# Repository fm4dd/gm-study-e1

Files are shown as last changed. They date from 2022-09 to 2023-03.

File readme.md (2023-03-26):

## GM-STUDY-E1

### Description

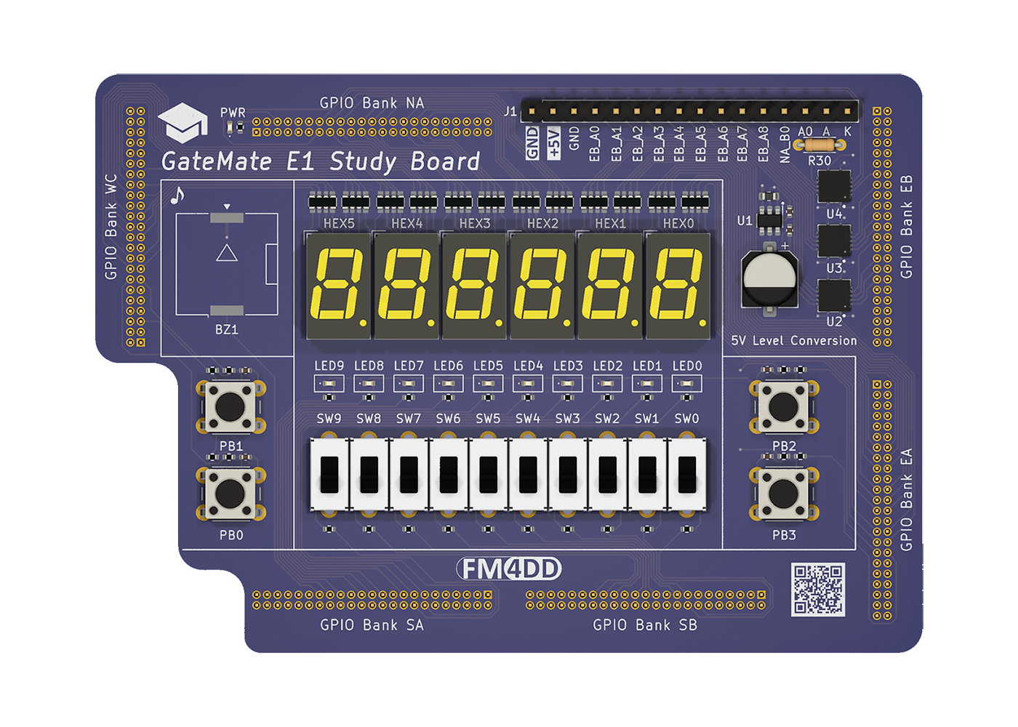
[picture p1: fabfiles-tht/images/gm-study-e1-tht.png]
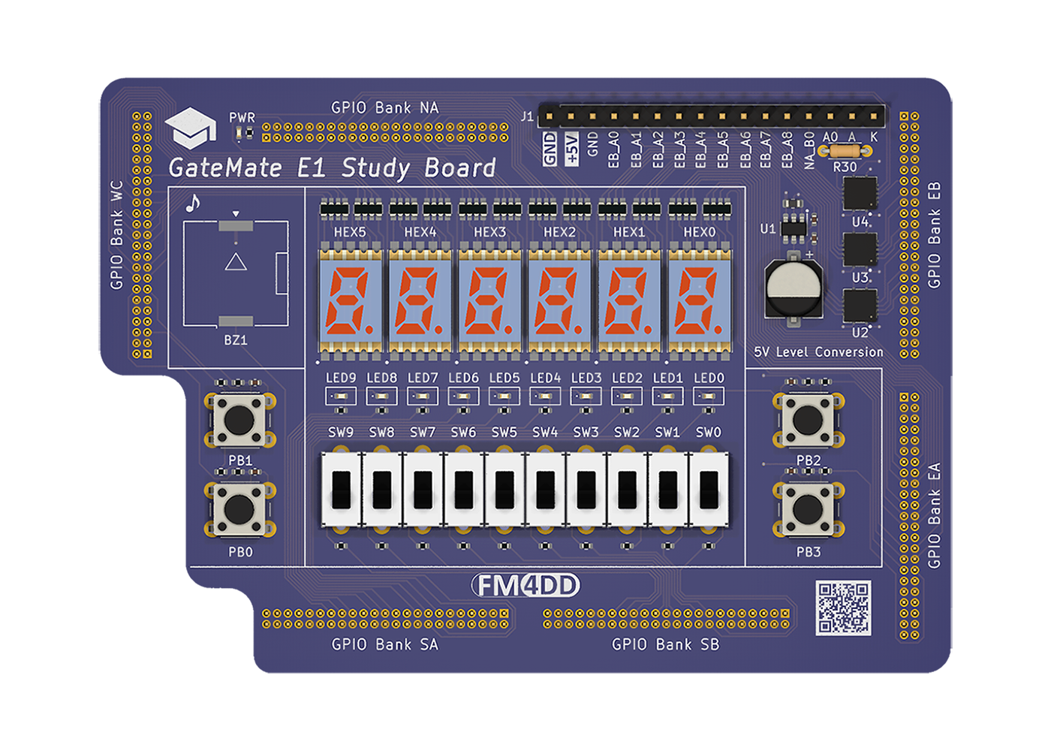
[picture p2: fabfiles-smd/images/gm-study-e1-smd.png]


The gm-study-e1 board is an application module board for the <a href="https://www.colognechip.com/programmable-logic/gatemate-evaluation-board/">GateMate FPGA evaluation board E1</a>, made by <a href="https://www.colognechip.com/">Cologne Chip</a>. It connects to the evaluation board through all six GPIO headers, and its main feature are the input/output components similar to popular FPGA trainer boards used for classroom teaching in electrical engineering and embedded systems education (e.g. Digilent Basys or Altera DE10-lite). These boards were created after successful design tests of the <a href="https://github.com/fm4dd/gm-proto-e1">gm-proto-e1</a> boards. The "gm-proto-e1" boards have only a few basic I/O, but provide a 2.54mm prototyping area for experimentation with GateMate E1.

### Overview

The gm-study-e1 boards provide:
- 4x push buttons
- 10x slide switches
- 10x LED
- 6x 7-Segment display modules (non-multiplexed)
- 1x 4 Khz buzzer
- J1 2.54mm pin header with 5V signal translation

The J1 pin header and pinout can connect 5V HD44780 character LCD display modules, or interface with breadboards for prototyping. There, the FPGA 2.5V IO signals are translated into 5V TTL levels, which can be used with an Arduino.

This design is registered under the OSHWA Open Source Hardware Self-Certification:  


### Hardware Versions

Two board variants have been designed: SMD, using 0.28" SMD 7-Segment modules, and THT for using slightly bigger 0.3" through-hole 7-Segment modules. For THT components, great care needs to be taken to cut pins flush during soldering, and prevent them from reaching components of the evaluation board below. The 1.27mm pitch GPIO connectors are offered with different distance spacers (2, 2.5 and 5mm), and the standard spacers achieve only 5mm total clearance.

Both gm-study-e1 application boards have been designed as a 100x70mm double-layer PCB with precision alignment of the six 46-pin 1.27mm pitch GPIO bank connectors (mates all 276 pins with the GateMate FPGA evaluation board E1 V3.1B).

#### Through-hole Design:

| Version | Gerber | Schema |
|---|---|---|
| 1.1 |[2030325-gm-study-e1-tht-gerber.zip](fabfiles-tht/v11/20230325-gm-study-e1-tht-gerber.zip) | [20230325-gm-proto-e1-schematic.pdf](fabfiles-tht/v11/20230325-gm-study-e1-tht-schematic.pdf) |

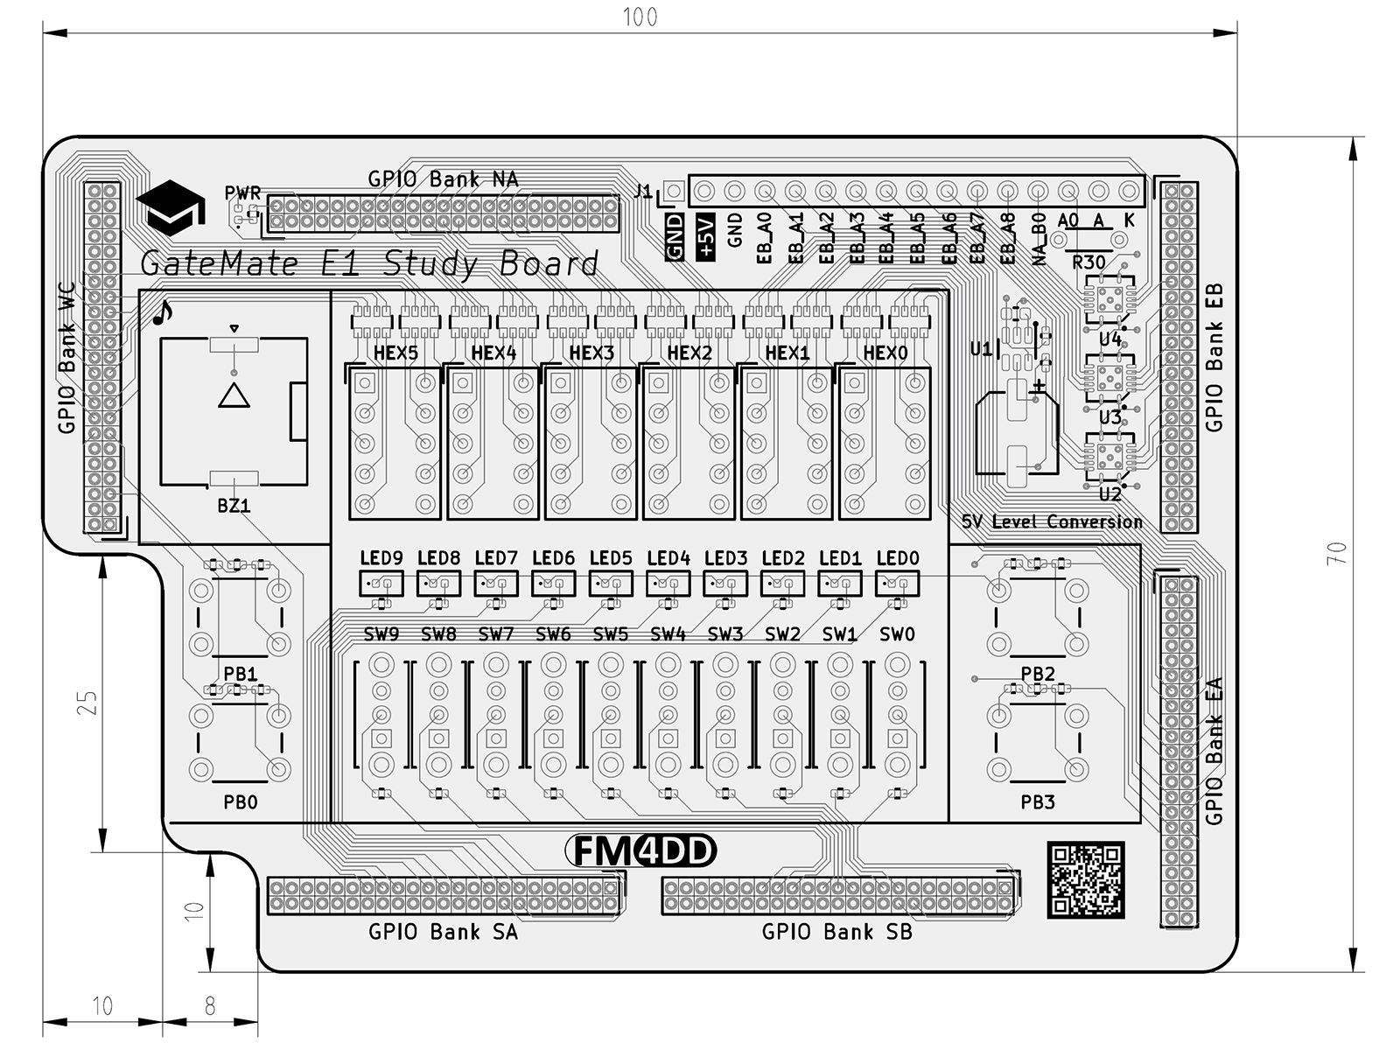
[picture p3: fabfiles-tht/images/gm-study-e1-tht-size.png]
 
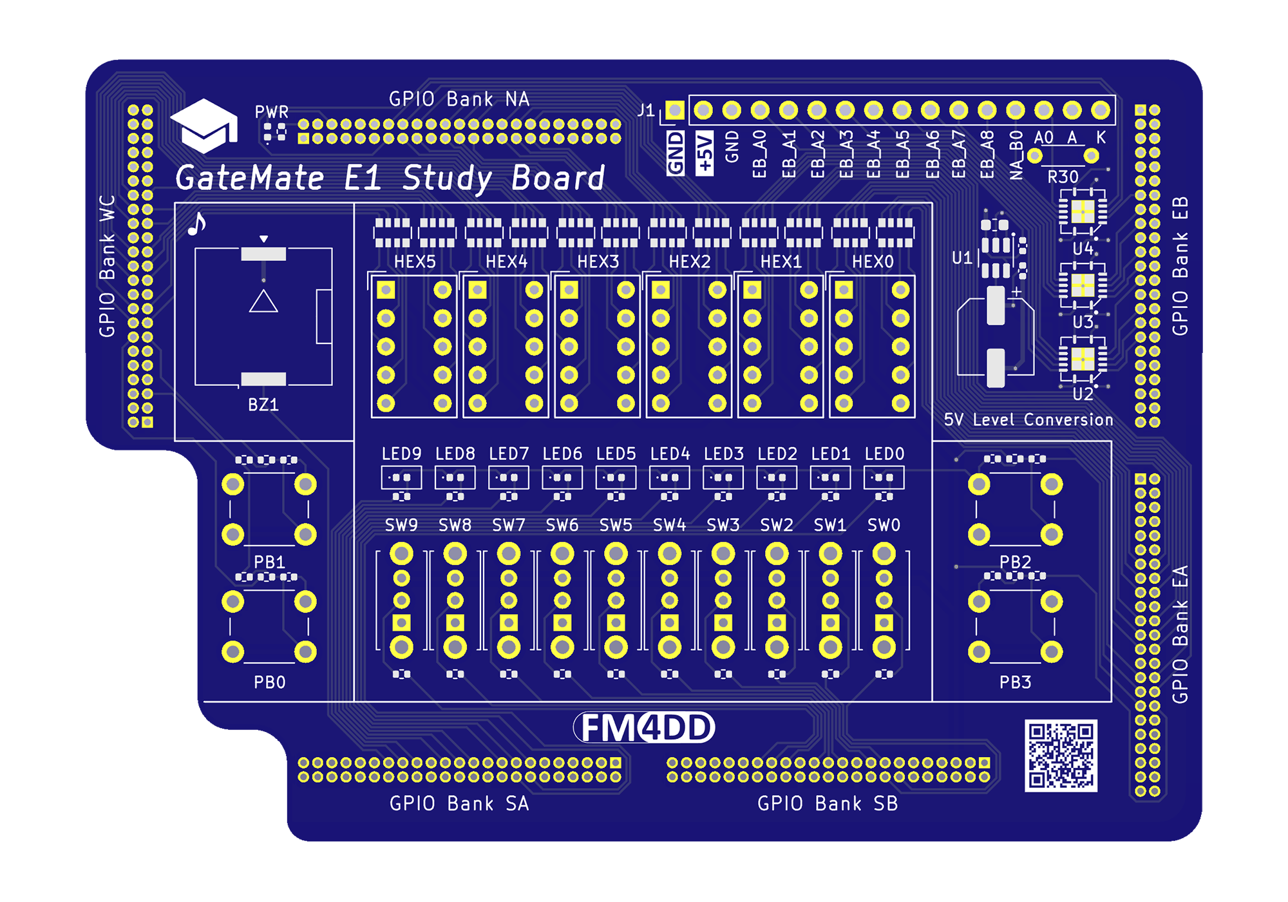
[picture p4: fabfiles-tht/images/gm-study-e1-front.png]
 

#### Surface-Mount Design:

| Version | Gerber | Schema |
|---|---|---|
| 1.1 |[20230326-gm-study-e1-smd-gerber.zip](fabfiles-smd/v11/20230326-gm-study-e1-smd-gerber.zip) | [20230326-gm-study-e1-smd-schematic.pdf](fabfiles-smd/v11/20230326-gm-study-e1-smd-schematic.pdf) |

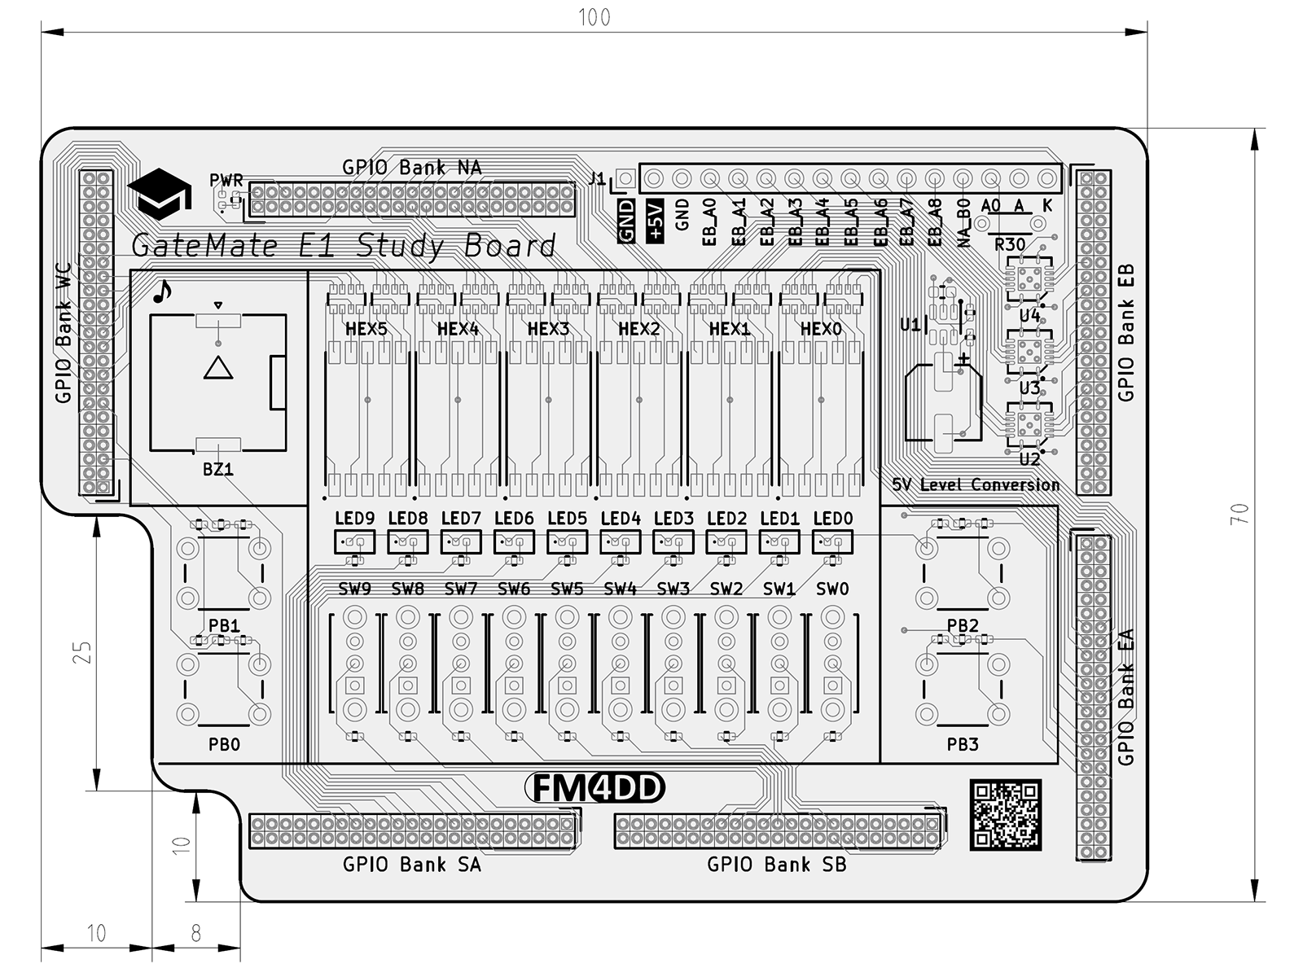
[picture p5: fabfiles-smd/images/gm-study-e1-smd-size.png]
 
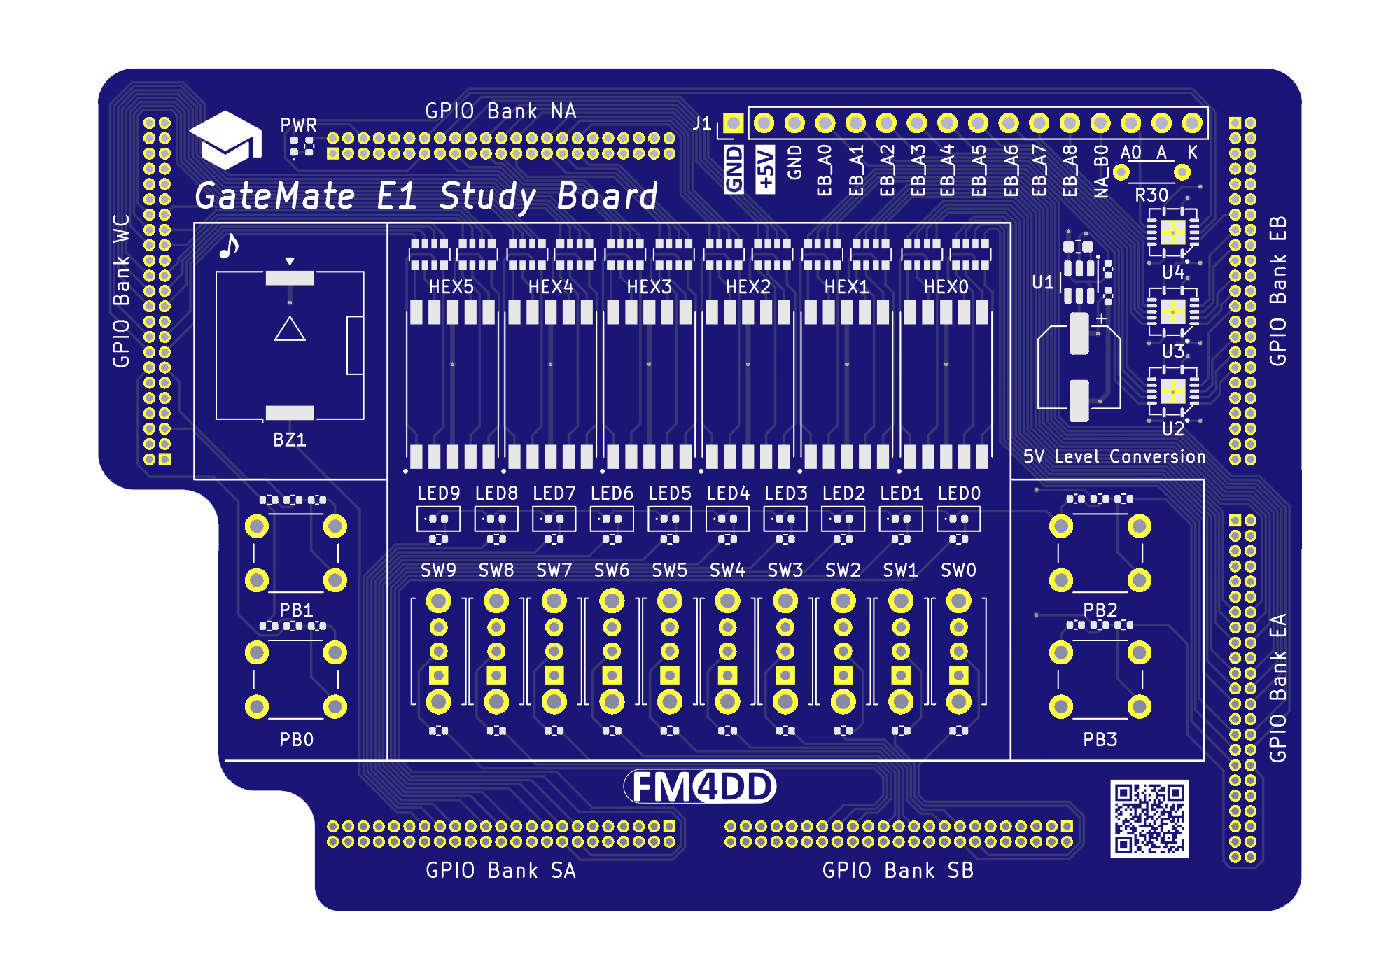
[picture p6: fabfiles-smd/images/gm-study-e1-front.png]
 

### Pin Assignments

Both variants (THT and SMD) have identical pinout, listed in [pin-assignment.md](pin-assignment.md).
They share a single constraints assignment file, located here: [gm-study-e1.ccf](examples/gm-study-e1.ccf)

### Example Code

The following code examples demonstrate the board input/output components for quick verification. The code has been tested with the pre-compiled opensource toolchain released through the GateMate support site at <a href="https://www.colognechip.com/mygatemate/">https://www.colognechip.com/mygatemate/</a>

| Language | Folder | Description |
|---|---|---|
| Verilog  |[blink](examples/blink) | blinks five LED's in a alternating pattern |
| Verilog  |[count](examples/count) | binary counter displayed on ten LED and six 7-Segment digits |
| Verilog  |[button](examples/button) | push button press changes LED frequency and light move direction  |
| Verilog  |[switch](examples/switch) | each slide switch turns its corresponding LED on or off |
| Verilog  |[sound](examples/sound) | play a song on the buzzer, show notes on LED and 7-segment digits |

### Board Pictures

The gm-study-e1 application board, running the switch demo.
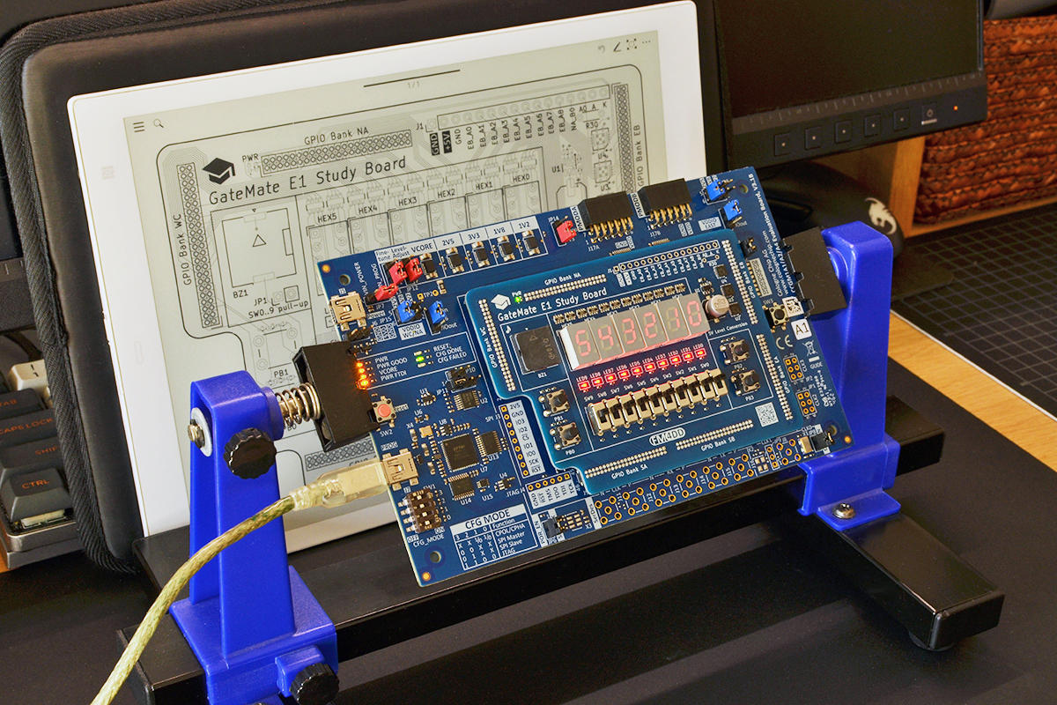
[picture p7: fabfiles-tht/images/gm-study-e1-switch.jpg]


The gm-study-e1 application board has been designed with KiCad version 6.0.
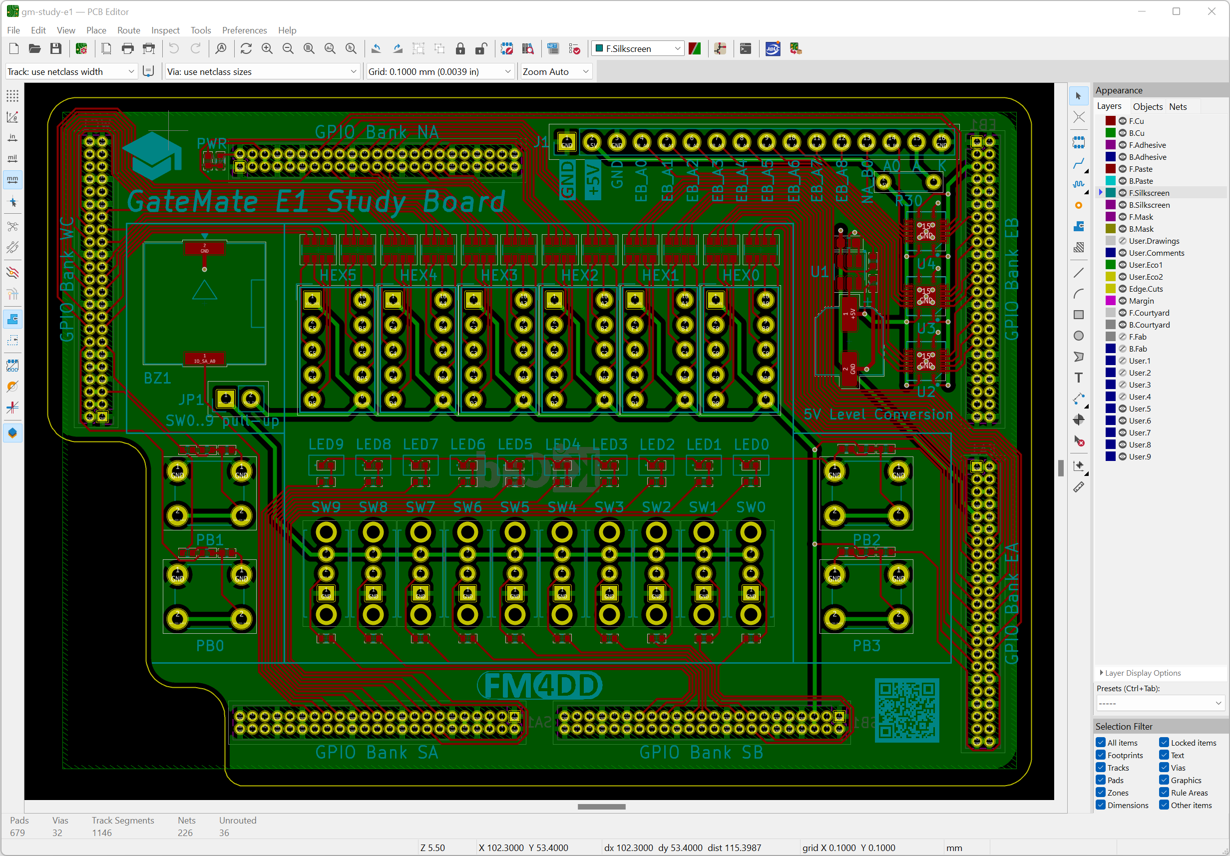
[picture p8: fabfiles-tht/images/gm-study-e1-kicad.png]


The gm-study-e1 application board, up close.
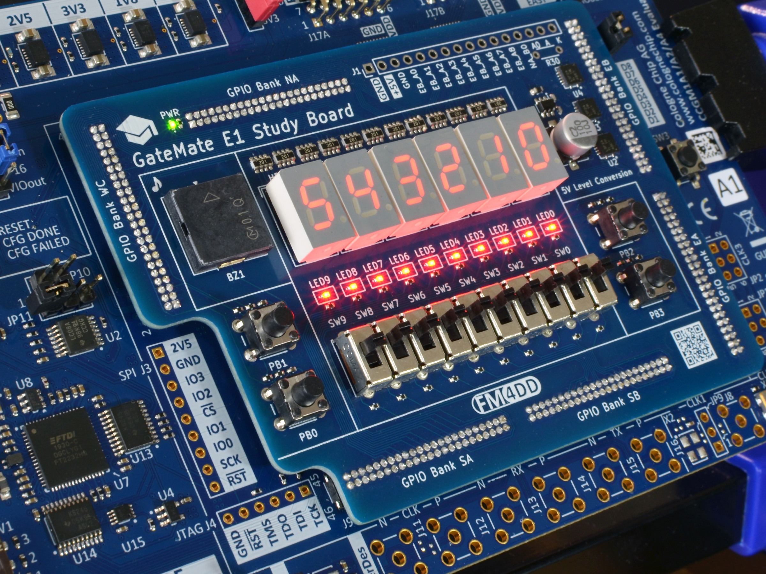
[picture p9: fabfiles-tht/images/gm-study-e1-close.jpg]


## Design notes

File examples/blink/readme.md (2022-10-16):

## GM-STUDY-E1 Example "blink"

This Verilog example program validates the function of the ten LED0..9. Using a clock divider for the 10MHz system clock, it alternates between LED0,2,4,6,8 and LED1,3,5,7,9 with a frequency of 2Hz.

### Usage

```
fm@nuc7vm2204:~/fpga/hardware/gm-study-e1/examples/blink$ make all
/home/fm/cc-toolchain-linux/bin/yosys/yosys -ql log/synth.log -p 'read -sv src/blink.v; synth_gatemate -top blink -vlog net/blink_synth.v'
/home/fm/cc-toolchain-linux/bin/p_r/p_r -i net/blink_synth.v -o blink -ccf ../gm-study-e1.ccf > log/impl.log
/usr/local/bin/openFPGALoader  -b gatemate_evb_jtag blink_00.cfg
Jtag frequency : requested 6.00MHz   -> real 6.00MHz
Load SRAM via JTAG: [==================================================] 100.00%
Done
Wait for CFG_DONE DONE
```

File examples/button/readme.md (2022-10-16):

## GM-STUDY-E1 Example "button"

This Verilog example program validates the function of the two push buttons PB0 and PB1. Push buttons are a bit tricky for the need of clock synchronisation and debounce. In this program, a running light moves over the ten LEDs. Push button PB0 controls the speed in 4 levels (16,8,4,2Hz), while push button PB1 controls the direction of the movement. The current state is displayed on the two 7-Segment modules: HEX4 displays the speed level 0..3, and HEX5 shows the direction F (forward) or b (backward).

### Usage

```
fm@nuc7vm2204:~/fpga/hardware/gm-study-e1/examples/button$ make all
/home/fm/cc-toolchain-linux/bin/yosys/yosys -ql log/synth.log -p 'read -sv src/button.v src/debounce.v src/hexdigit.v; synth_gatemate -top button -vlog net/button_synth.v'
/home/fm/cc-toolchain-linux/bin/p_r/p_r -i net/button_synth.v -o button -ccf ../gm-study-e1.ccf > log/impl.log
/usr/local/bin/openFPGALoader  -b gatemate_evb_jtag button_00.cfg
Jtag frequency : requested 6.00MHz   -> real 6.00MHz  
Load SRAM via JTAG: [==================================================] 100.00%
Done
Wait for CFG_DONE DONE
```

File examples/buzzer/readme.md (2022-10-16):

## GM-STUDY-E1 Example "buzzer"

This Verilog example program validates the function of the buzzer sound module. A press on each of the four push buttons creates a different frequency, which outputs a different tone on the buzzer. Each button lights up its equivalent LED, and the button number is displayed on two of the six 7-segment display modules as b0..b3.

### Usage

```
fm@nuc7vm2204:~/fpga/hardware/gm-study-e1/examples/buzzer$ make all
/home/fm/cc-toolchain-linux/bin/yosys/yosys -ql log/synth.log -p 'read -sv src/buzzer.v src/hexdigit.v; synth_gatemate -top buzzer -vlog net/buzzer_synth.v'
/home/fm/cc-toolchain-linux/bin/p_r/p_r -i net/buzzer_synth.v -o buzzer -ccf ../gm-study-e1.ccf > log/impl.log
/usr/local/bin/openFPGALoader  -b gatemate_evb_jtag buzzer_00.cfg
Jtag frequency : requested 6.00MHz   -> real 6.00MHz
Load SRAM via JTAG: [==================================================] 100.00%
Done
Wait for CFG_DONE DONE
```

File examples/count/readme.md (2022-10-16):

## GM-STUDY-E1 Example "count"

This Verilog example program is a binary counter, displayed in binary on the ten LED's, and in hexadecimal on 7-Segment digits HEX0..HEX3. The hex digits can be enabled or disabled by slide switches SW0 and SW1. The counter runs at 1Hz, and the 7-segment decimal points pulse the counter clock. The counter clock is derived from the 10MHz system clock of the evaluation board.

### Usage

```
fm@nuc7vm2204:~/fpga/hardware/gm-study-e1/examples/count$ make all
/home/fm/cc-toolchain-linux/bin/yosys/yosys -ql log/synth.log -p 'read -sv src/count.v src/hexdigit.v; synth_gatemate -top count -vlog net/count_synth.v'
/home/fm/cc-toolchain-linux/bin/p_r/p_r -i net/count_synth.v -o count -ccf ../gm-study-e1.ccf > log/impl.log
/usr/local/bin/openFPGALoader  -b gatemate_evb_jtag count_00.cfg
Jtag frequency : requested 6.00MHz   -> real 6.00MHz  
Load SRAM via JTAG: [==================================================] 100.00%
Done
Wait for CFG_DONE DONE
```

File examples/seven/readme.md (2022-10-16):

## GM-STUDY-E1 Example "seven"

This Verilog example program validates the function of the six 7-segment display modules. This program works without a clock. Turning a slide switch "on" enables the respective board LED0..9. For switches SW0..5, turning it on also lights up the respective 7-segment module with its number. Turning slide switch SW0..5 off will light up all LED segments of the corresponding 7-segment module.

### Usage

```
fm@nuc7vm2204:~/fpga/hardware/gm-study-e1/examples/seven$ make all
/home/fm/cc-toolchain-linux/bin/yosys/yosys -ql log/synth.log -p 'read -sv src/hexdigit.v src/seven.v; synth_gatemate -top seven -vlog net/seven_synth.v'
/home/fm/cc-toolchain-linux/bin/p_r/p_r -i net/seven_synth.v -o seven -ccf ../gm-study-e1.ccf > log/impl.log
/usr/local/bin/openFPGALoader  -b gatemate_evb_jtag seven_00.cfg
Jtag frequency : requested 6.00MHz   -> real 6.00MHz  
Load SRAM via JTAG: [==================================================] 100.00%
Done
Wait for CFG_DONE DONE
```

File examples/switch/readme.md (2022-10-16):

## GM-STUDY-E1 Example "switch"

This Verilog example program validates the function of the ten slide switches. This program works without a clock. Turning a slide switch "on" enables the respective board LED0..9. For switches SW0..5, turning it on also lights up the respective 7-segment module with its number.

### Usage

```
fm@nuc7vm2204:~/fpga/hardware/gm-study-e1/examples/switch$ make all
/home/fm/cc-toolchain-linux/bin/yosys/yosys -ql log/synth.log -p 'read -sv src/hexdigit.v src/switch.v; synth_gatemate -top switch -vlog net/switch_synth.v'
/home/fm/cc-toolchain-linux/bin/p_r/p_r -i net/switch_synth.v -o switch -ccf ../gm-study-e1.ccf > log/impl.log
/usr/local/bin/openFPGALoader  -b gatemate_evb_jtag switch_00.cfg
Jtag frequency : requested 6.00MHz   -> real 6.00MHz
Load SRAM via JTAG: [==================================================] 100.00%
Done
Wait for CFG_DONE DONE
```

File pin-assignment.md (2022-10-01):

## gm-study-e1 Pin Assignment

Note: Components are prefixed with "st" to identify them belonging to the gm-study-e1 application board.

### 10x LED output "stled" on IO Bank SA

Name     | Location | Direction | Standard | comment
---------|----------|-----------|----------|---------
stled[0] | IO_SA_B7 | output    | 2.5V     |
stled[1] | IO_SA_B8 | output    | 2.5V     |
stled[2] | IO_SA_A8 | output    | 2.5V     |
stled[3] | IO_SA_A7 | output    | 2.5V     |
stled[4] | IO_SA_A6 | output    | 2.5V     |
stled[5] | IO_SA_A5 | output    | 2.5V     |
stled[6] | IO_SA_A4 | output    | 2.5V     |
stled[7] | IO_SA_A3 | output    | 2.5V     |
stled[8] | IO_SA_A2 | output    | 2.5V     |
stled[9] | IO_SA_A1 | output    | 2.5V     |

### 6x 7-Segment Digits "sthex"

#### Segment 0 on IO Bank EA

Name      | Location | Direction | Standard | comment
----------|----------|-----------|----------|-----------
sthex0[0] | IO_EA_A1 | output    | 2.5V     | hex0 - DP
sthex0[1] | IO_EA_A2 | output    | 2.5V     | hex0 - A
sthex0[2] | IO_EA_A3 | output    | 2.5V     | hex0 - B
sthex0[3] | IO_EA_A4 | output    | 2.5V     | hex0 - C
sthex0[4] | IO_EA_A5 | output    | 2.5V     | hex0 - D
sthex0[5] | IO_EA_A6 | output    | 2.5V     | hex0 - E
sthex0[6] | IO_EA_A7 | output    | 2.5V     | hex0 - F
sthex0[7] | IO_EA_A8 | output    | 2.5V     | hex0 - G

#### Segment 1 on IO Bank EA

Name      | Location | Direction | Standard | comment
----------|----------|-----------|----------|--------
sthex1[0] | IO_EA_B8 | output    | 2.5V     | hex1 - DP
sthex1[1] | IO_EA_B7 | output    | 2.5V     | hex1 - A
sthex1[2] | IO_EA_B6 | output    | 2.5V     | hex1 - B
sthex1[3] | IO_EA_B5 | output    | 2.5V     | hex1 - C
sthex1[4] | IO_EA_B4 | output    | 2.5V     | hex1 - D
sthex1[5] | IO_EA_B3 | output    | 2.5V     | hex1 - E
sthex1[6] | IO_EA_B2 | output    | 2.5V     | hex1 - F
sthex1[7] | IO_EA_B1 | output    | 2.5V     | hex1 - G

#### Segment 2 on IO Bank NA

Name      | Location | Direction | Standard | comment
----------|----------|-----------|----------|--------
sthex2[0] | IO_NA_B1 | output    | 2.5V     | hex2 - DP
sthex2[1] | IO_NA_B2 | output    | 2.5V     | hex2 - A
sthex2[2] | IO_NA_B3 | output    | 2.5V     | hex2 - B
sthex2[3] | IO_NA_B4 | output    | 2.5V     | hex2 - C
sthex2[4] | IO_NA_B5 | output    | 2.5V     | hex2 - D
sthex2[5] | IO_NA_B6 | output    | 2.5V     | hex2 - E
sthex2[6] | IO_NA_B7 | output    | 2.5V     | hex2 - F
sthex2[7] | IO_NA_B8 | output    | 2.5V     | hex2 - G

#### Segment 3 on IO Bank NA

Name      | Location | Direction | Standard | comment
----------|----------|-----------|----------|--------
sthex3[0] | IO_NA_A8 | output    | 2.5V     | hex3 - DP
sthex3[1] | IO_NA_A7 | output    | 2.5V     | hex3 - A
sthex3[2] | IO_NA_A6 | output    | 2.5V     | hex3 - B
sthex3[3] | IO_NA_A5 | output    | 2.5V     | hex3 - C
sthex3[4] | IO_NA_A4 | output    | 2.5V     | hex3 - D
sthex3[5] | IO_NA_A3 | output    | 2.5V     | hex3 - E
sthex3[6] | IO_NA_A2 | output    | 2.5V     | hex3 - F
sthex3[7] | IO_NA_A1 | output    | 2.5V     | hex3 - G

#### Segment 4 on IO Bank WC

Name      | Location | Direction | Standard | comment
----------|----------|-----------|----------|--------
sthex4[0] | IO_WC_B1 | output    | 2.5V     | hex4 - DP
sthex4[1] | IO_WC_B2 | output    | 2.5V     | hex4 - A
sthex4[2] | IO_WC_B3 | output    | 2.5V     | hex4 - B
sthex4[3] | IO_WC_B4 | output    | 2.5V     | hex4 - C
sthex4[4] | IO_WC_B5 | output    | 2.5V     | hex4 - D
sthex4[5] | IO_WC_B6 | output    | 2.5V     | hex4 - E
sthex4[6] | IO_WC_B7 | output    | 2.5V     | hex4 - F
sthex4[7] | IO_WC_B8 | output    | 2.5V     | hex4 - G

#### Segment 5 on IO Bank WC

Name      | Location | Direction | Standard | comment
----------|----------|-----------|----------|--------
sthex5[0] | IO_WC_A8 | output    | 2.5V     | hex5 - DP
sthex5[1] | IO_WC_A7 | output    | 2.5V     | hex5 - A
sthex5[2] | IO_WC_A6 | output    | 2.5V     | hex5 - B
sthex5[3] | IO_WC_A5 | output    | 2.5V     | hex5 - C
sthex5[4] | IO_WC_A4 | output    | 2.5V     | hex5 - D
sthex5[5] | IO_WC_A3 | output    | 2.5V     | hex5 - E
sthex5[6] | IO_WC_A2 | output    | 2.5V     | hex5 - F
sthex5[7] | IO_WC_A1 | output    | 2.5V     | hex5 - G

### 1x Buzzer output "stbuz" on IO Bank SA

Name      | Location | Direction | Standard | comment
----------|----------|-----------|----------|--------
stbuz     | IO_SA_A0 | output    | 2.5V     |

### 10x Slide Switch input "stswi" on IO Bank SB

Name     | Location | Direction | Standard | comment
---------|----------|-----------|----------|--------
stswi[0] | IO_SB_B7 | input     | 2.5V     |
stswi[1] | IO_SB_B8 | input     | 2.5V     |
stswi[2] | IO_SB_A7 | input     | 2.5V     |
stswi[3] | IO_SB_A6 | input     | 2.5V     |
stswi[4] | IO_SB_A7 | input     | 2.5V     |
stswi[5] | IO_SB_A4 | input     | 2.5V     |
stswi[6] | IO_SB_A3 | input     | 2.5V     |
stswi[7] | IO_SB_A2 | input     | 2.5V     |
stswi[8] | IO_SB_A1 | input     | 2.5V     |
stswi[9] | IO_SB_A0 | input     | 2.5V     |

### 4x Push Buttons "stbtn" on IO Bank WC, EA

Name     | Location | Direction | Standard | comment
---------|----------|-----------|----------|--------
stbtn[0] | IO_WC_B0 | input     | 2.5V     |
stbtn[1] | IO_WC_A0 | input     | 2.5V     |
stbtn[2] | IO_EA_A0 | input     | 2.5V     |
stbtn[3] | IO_EA_B0 | input     | 2.5V     |

### 11 pins on J1, 5V character LCD-compatible

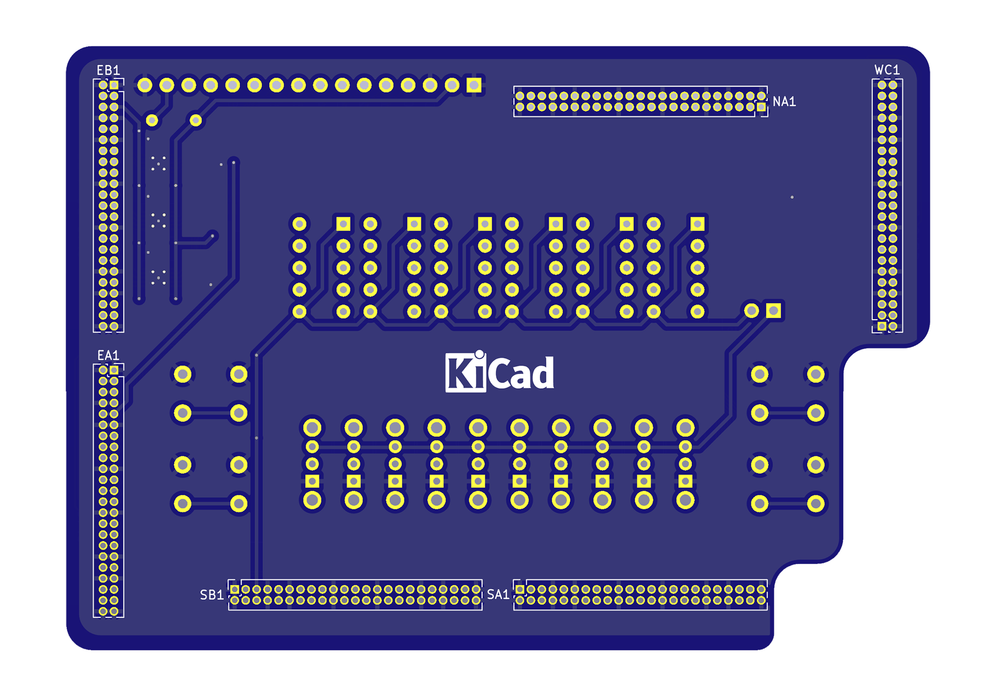
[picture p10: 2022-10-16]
fabfiles-tht/images/gm-study-e1-back.png

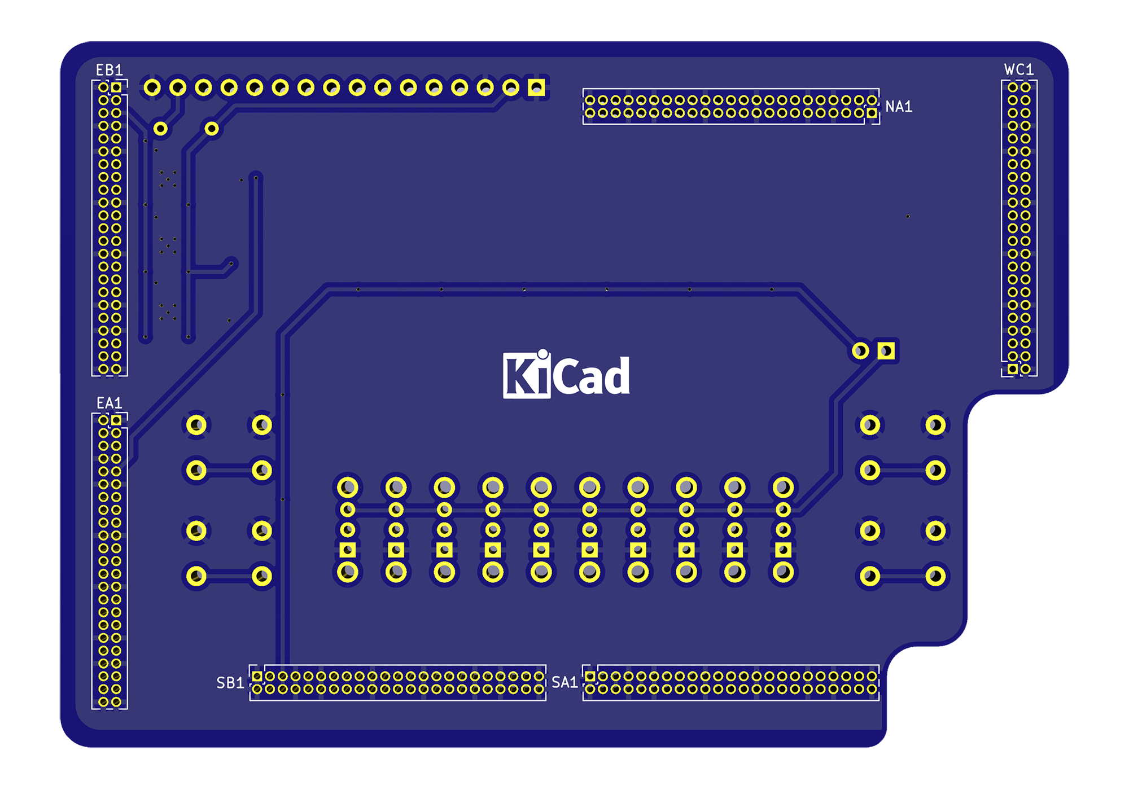
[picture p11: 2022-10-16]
fabfiles-smd/images/gm-study-e1-back.png

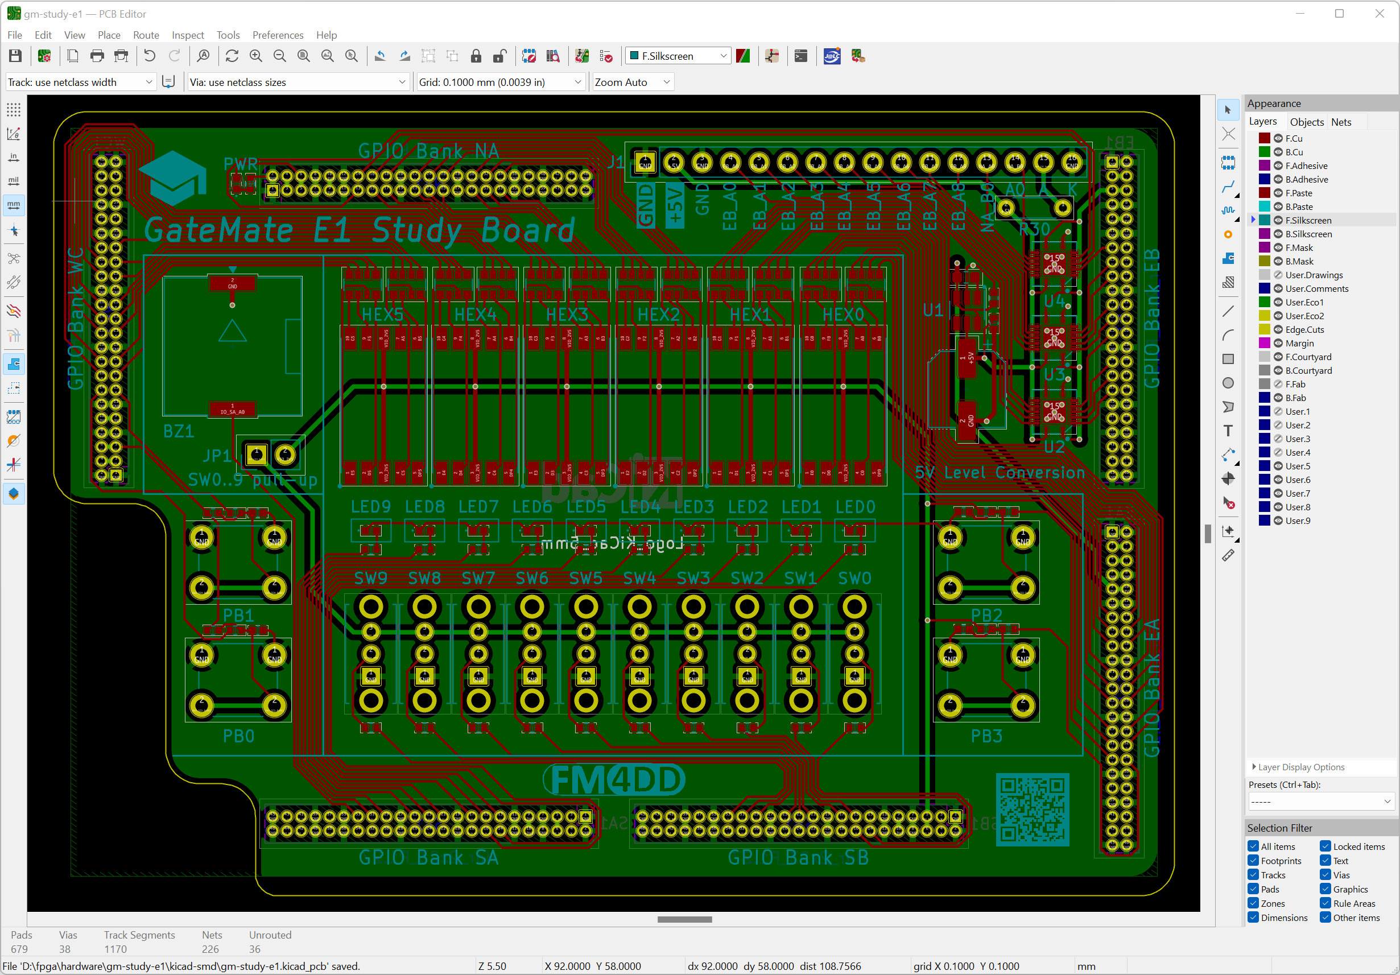
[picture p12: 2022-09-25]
fabfiles-smd/images/gm-study-e1-kicad.png

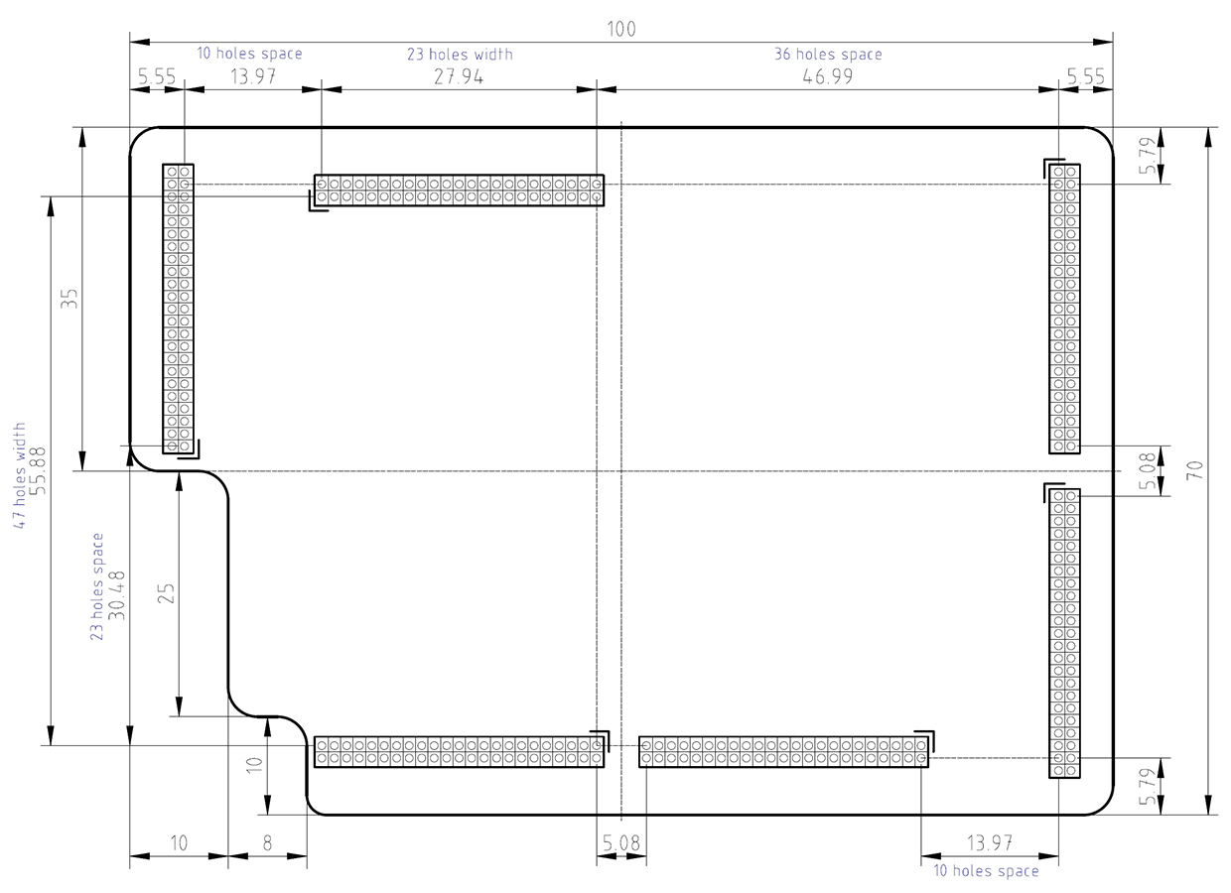
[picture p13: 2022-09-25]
fabfiles-tht/images/gm-study-e1-connectors.png

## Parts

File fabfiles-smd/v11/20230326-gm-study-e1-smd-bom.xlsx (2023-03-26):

Comment | Designator | Footprint | JLCPCB Part #（optional）
BZ1 PKLCS1212E4001-R1 | BZ1 | Buzzer_Murata_PKLCS1212E | C113159
10uF 0402CG150J500NT | C1,C2 | C_0402_1005Metric | C30274
1u C0402C104K4RECAUTO | C3,C4,C5,C6 | C_0402_1005Metric | C52923
100uF | C7 | CP_Elec_6.3x5.3 | C134749
0.1u C0402C103K4RECAUTO | C8,C9,C10,C11,C12,C13 | C_0402_1005Metric | C1525
100K 0402WGF1003TCE | R1,R2,R3,R4,R5,R6,R7,R8,R9,R10 | R_0402_1005Metric | C25741
200R 0402WGF2000TCE | R11,R12,R13,R14,R15,R16,R17,R18,R19,R20 | R_0402_1005Metric | C25087
200K 0402WGF2003TCE | R21,R22,R23,R24 | R_0402_1005Metric | C25764
33R 0402WGF330JTCE | R25,R26,R27,R28 | R_0402_1005Metric | C25105
160R 0402WGF1600TCE | R29 | R_0402_1005Metric | C270641
100R | R30 | R_0402_1005Metric | C25076
10K | R31,R32,R33 | R_0402_1005Metric | C25744
180R 4D03WGJ0181T5E | RA1,RA2,RA3,RA4,RA5,RA6,RA7,RA8,RA9,RA10,RA11,RA12 | R_Array_Concave_4x0603 0603_X4 | C12003
SGM6603-5.0 | U1 | SOT-23-6 | C79689
TXB0104 | U2,U3,U4 | S-PVQFN-N14-1EP_3.65x3.65_P0.5_EP2.05x2.05 | C400708
red TJ-S1005SW4TGLC2R-A5 | LED0,LED1,LED2,LED3,LED4,LED5,LED6,LED7,LED8,LED9 | LED_0402_FPGA | C273598
green TJ-S1005SW4TGLC7K-A5 | LED10 | LED_0402_FPGA | C273601
4.7uH | L1 | L_0603_1608Metric | C1034
7SEG SMD SLS0281FR1A1GD | HEX0,HEX1,HEX2,HEX3,HEX4,HEX5 | 7SEG SMD SLS0281FR1A1GD | C225994

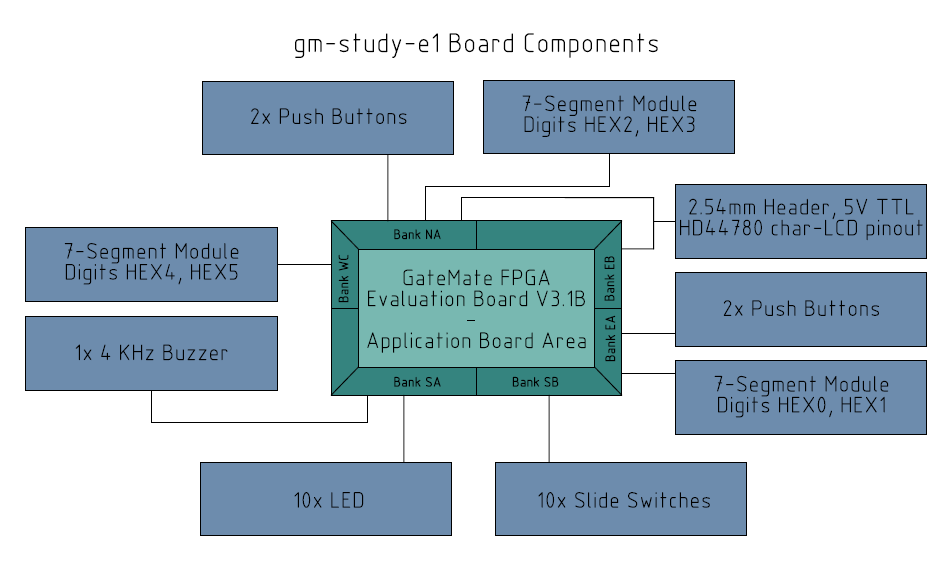
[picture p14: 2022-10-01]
fabfiles-tht/images/study-board-components.png

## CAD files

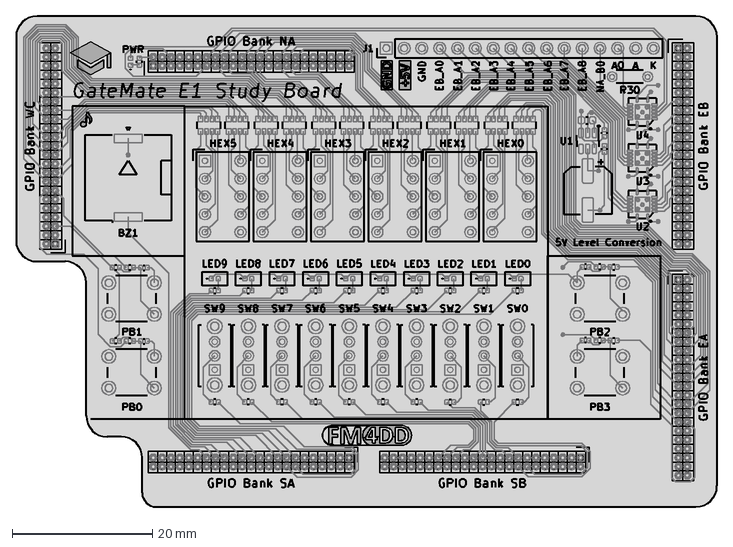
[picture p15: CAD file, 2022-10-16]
cad/gm-study-e1-dimensions.dxf
100.0 x 70.0 mm

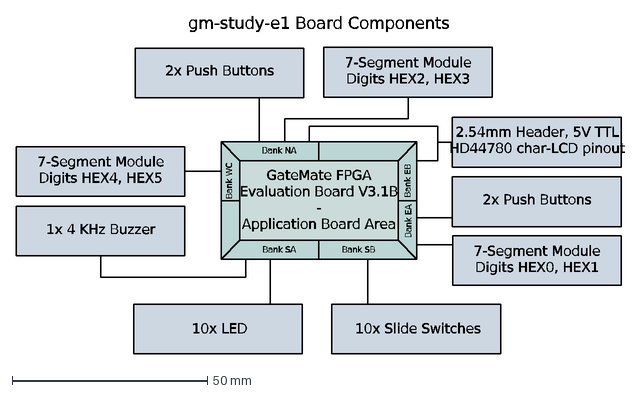
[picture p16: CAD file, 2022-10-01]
cad/gm-study-e1-blocks.dxf
gm-study-e1 Board Components
7-Segment Module Digits HEX0, HEX1
7-Segment Module Digits HEX2, HEX3
7-Segment Module Digits HEX4, HEX5
1x 4 KHz Buzzer
10x Slide Switches
10x LED
2x Push Buttons
2.54mm Header, 5V TTL HD44780 char-LCD pinout
Bank EA
Bank EB
Bank WC
Bank NA
Bank SA
Bank SB
GateMate FPGA Evaluation Board V3.1B - Application Board Area

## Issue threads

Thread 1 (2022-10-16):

IO bank NA gives intermittent pin contact for B1 and B2

fm4dd, 2022-10-16:
The app boards get intermittent pin contact for pins IO_NA_B1 and IO_NA_B2. The boards have been checked to be OK, and the issue occurs across different app boards and board types.  The signal measurements on the E1 NA bank connector surface-mount solder joints confirm a good signal. The suspected root cause is at the evaluation board E1 bank connector for Bank NA.

I would need a second E1 board to fully confirm it. I may have a weak connector. The E1 evaluation boards BCP thickness of 1.2 mm is rather weak, which lends to bending.

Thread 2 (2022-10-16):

Brighten up the 7-segment LED modules

fm4dd, 2022-10-16:
The resistor bank RA values for the HDSP-7501 7-segment LED modules are too strong at 200 Ohm. They should be reduced to 180/160 Ohm.

fm4dd, 2023-03-25:
Improved in new PCB revision v1.1 commit [6197a5e](https://github.com/fm4dd/gm-study-e1/commit/6197a5efbae6ce4afec6cf6b41b33c2dd8c14bda)

Closed 2023-03-25.

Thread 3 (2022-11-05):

5V signal level conversion failure on connector J1

fm4dd, 2022-11-05:
Per Texas Instruments application note [SLV675B](https://www.ti.com/lit/an/slva675b/slva675b.pdf?ts=1667636725930), the signal lines operated by the TI LSF204 level translation circuits (U2,U3,U4) need pull-up resistors. They need to be added in for high side (B-side), the low-side (A-side) is recommended for signal integrity. Need to verify and test the signal levels on J1 in detail. 5V power is present.

fm4dd, 2023-02-22:
In further testing, the initial Texas Instruments LSF204 IC is not suitable for the application design. I successfully tested Texas Instruments TXB0104 IC's instead, having identical footprints allowing for simple change. The TCB0104 has been validated through the [PMOD-CharLCD](https://github.com/fm4dd/pmod-charlcd) board.

Side note: Many character LCD's only need the 5V for power, while their data lines operating on signal levels well below 3V and don't necessarily need the signal shifting to 5V. Adding this function is still a good way for me to validate such a design because LCD pin headers are versatile, and easy to be used as generic ports e.g. for breadboard expansion.

Closed 2023-02-22.

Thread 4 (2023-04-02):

Buzzer bz1 low sound volume

fm4dd, 2023-04-02:
The volume of buzzer bz1 is rather low. This could improve by raising the GPIO signal voltage. There is still one free signal path A1/B1 on U2...

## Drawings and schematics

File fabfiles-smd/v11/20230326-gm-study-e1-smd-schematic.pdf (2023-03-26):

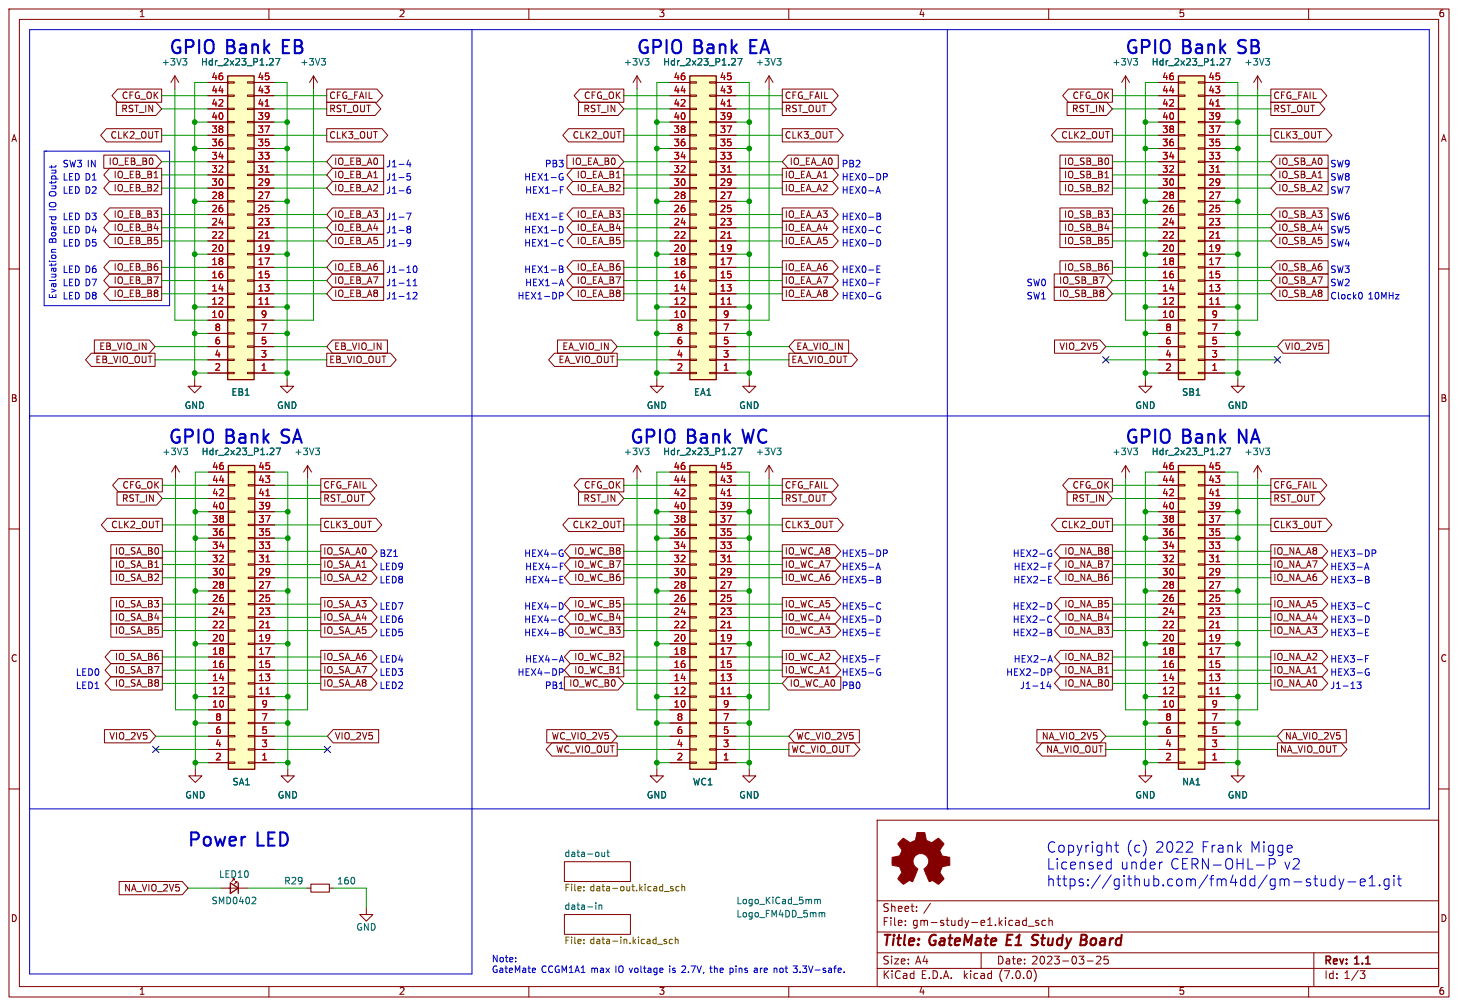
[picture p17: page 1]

HEX4-A
Note: GateMate CCGM1A1 max IO voltage is 2.7V, the pins are not 3.3V-safe.HEX5-G

data-out File: data-out.kicad_sch

https://github.com/fm4dd/gm-study-e1.git

File: gm-study-e1.kicad_sch Sheet: / data-in File: data-in.kicad_sch

Id: 1/3 Title: GateMate E1 Study Board

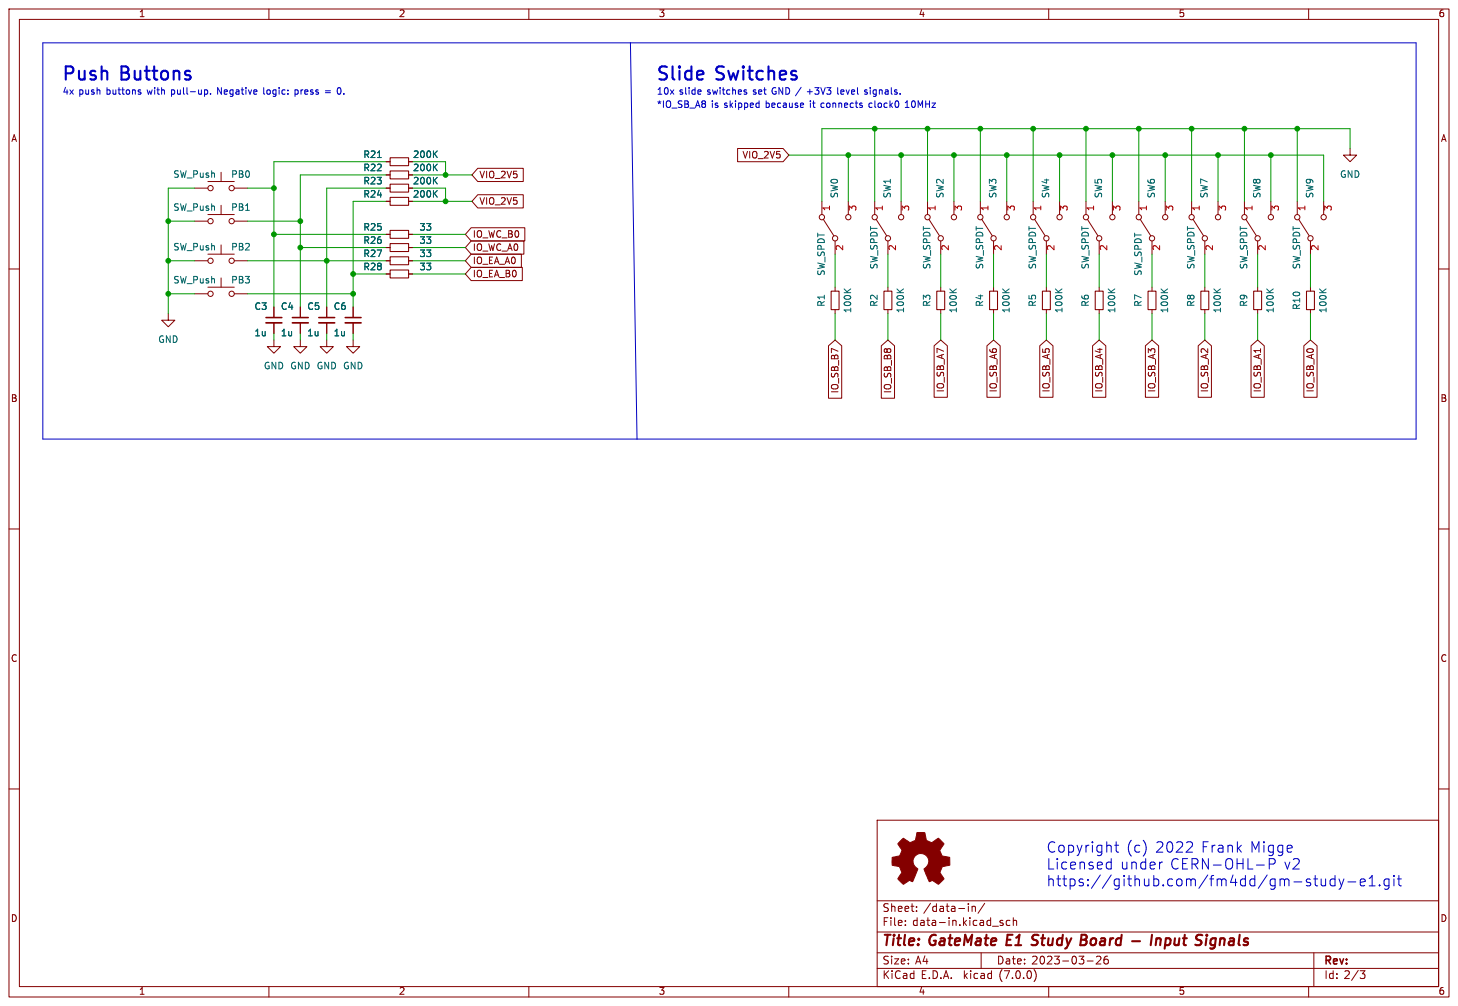
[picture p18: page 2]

10x slide switches set GND / +3V3 level signals.

Copyright (c) 2022 Frank Migge
https://github.com/fm4dd/gm-study-e1.git

File: data-in.kicad_sch Sheet: /data-in/
Id: 2/3 Title: GateMate E1 Study Board - Input Signals

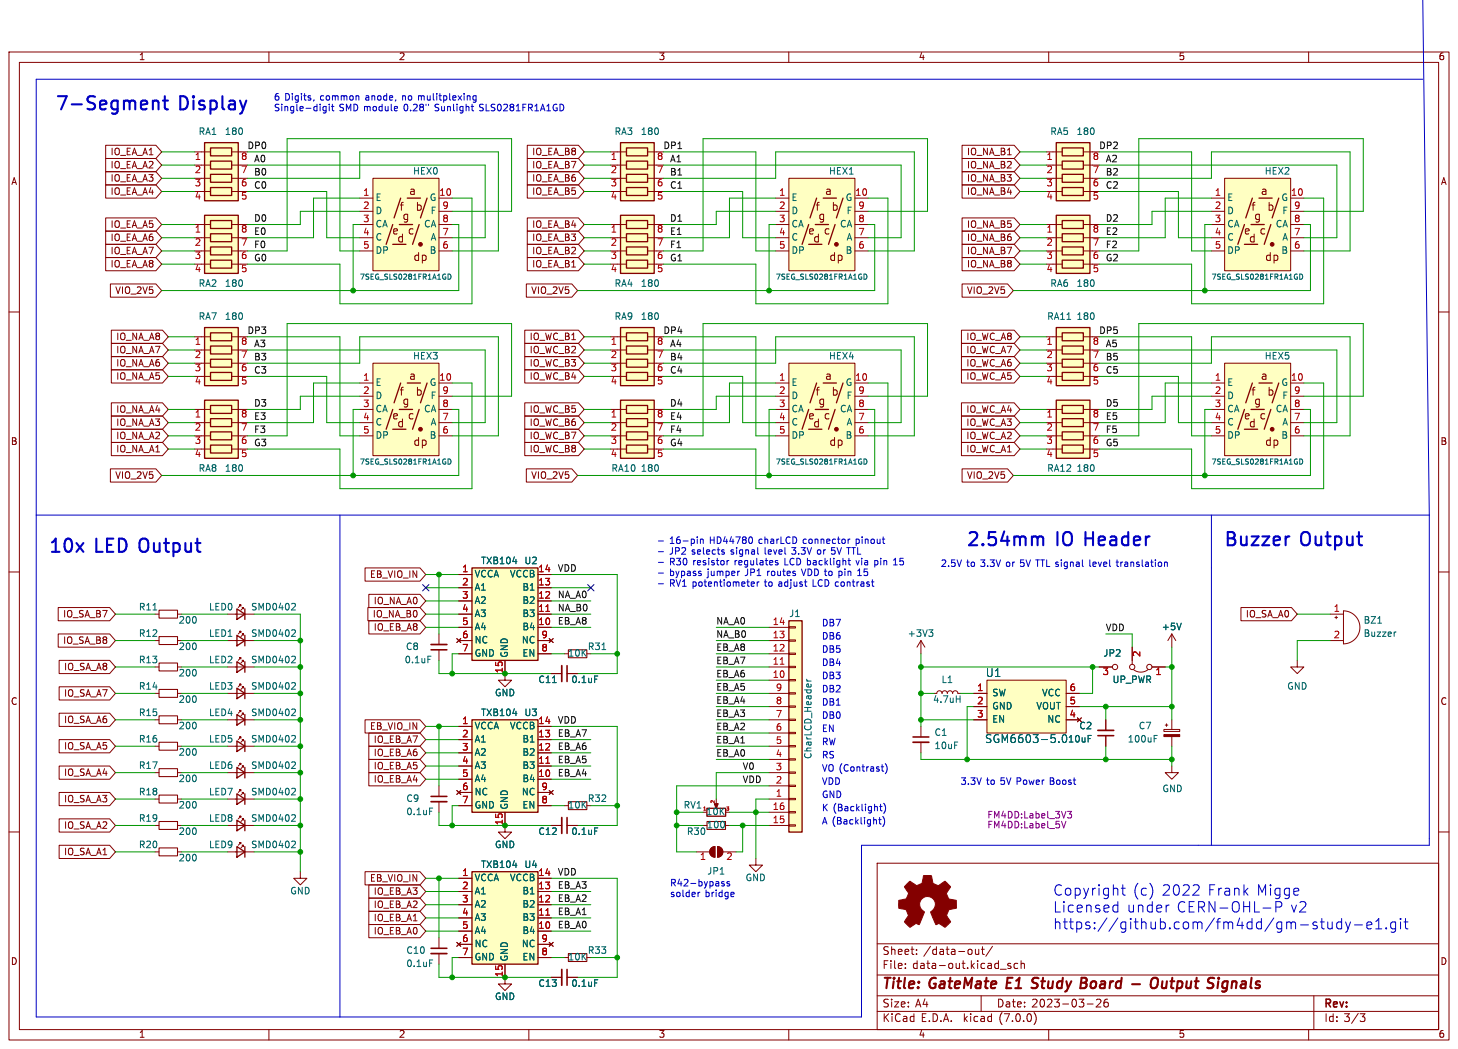
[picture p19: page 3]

- bypass jumper JP1 routes VDD to pin 15

2.5V to 3.3V or 5V TTL signal level translation C2

3.3V to 5V Power Boost RW

https://github.com/fm4dd/gm-study-e1.git

Id: 3/3 Title: GateMate E1 Study Board - Output Signals

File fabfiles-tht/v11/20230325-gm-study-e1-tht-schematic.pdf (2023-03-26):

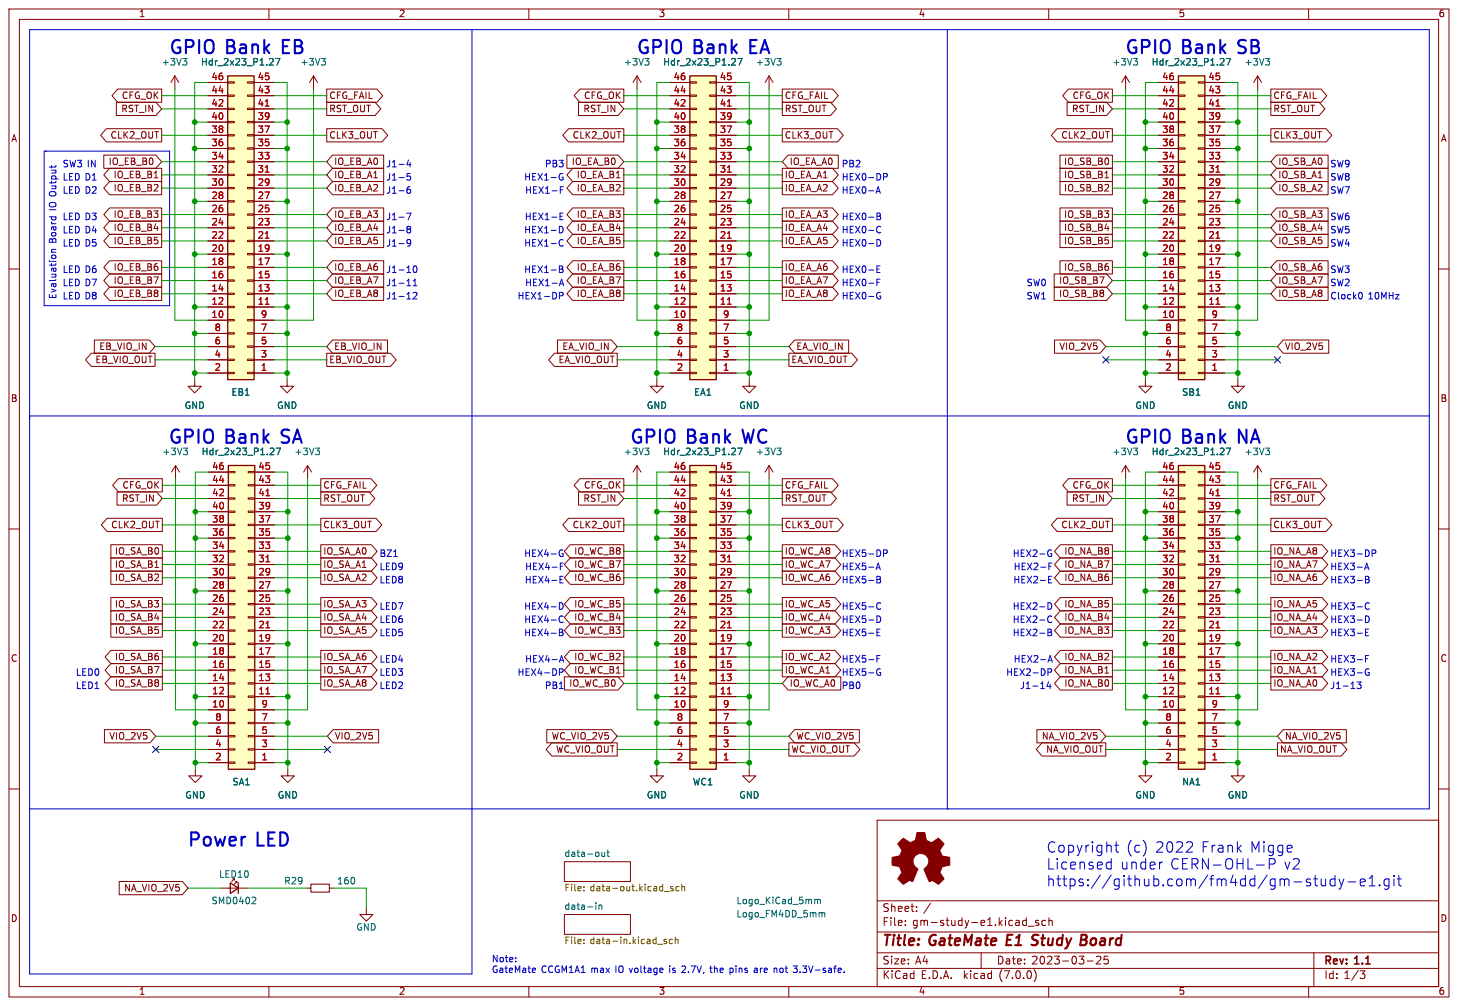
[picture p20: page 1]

SW9 HEX3-DP HEX5-C GPIO Bank WC

data-out File: data-out.kicad_sch

https://github.com/fm4dd/gm-study-e1.git

File: gm-study-e1.kicad_sch Sheet: / data-in File: data-in.kicad_sch

Id: 1/3 Title: GateMate E1 Study Board

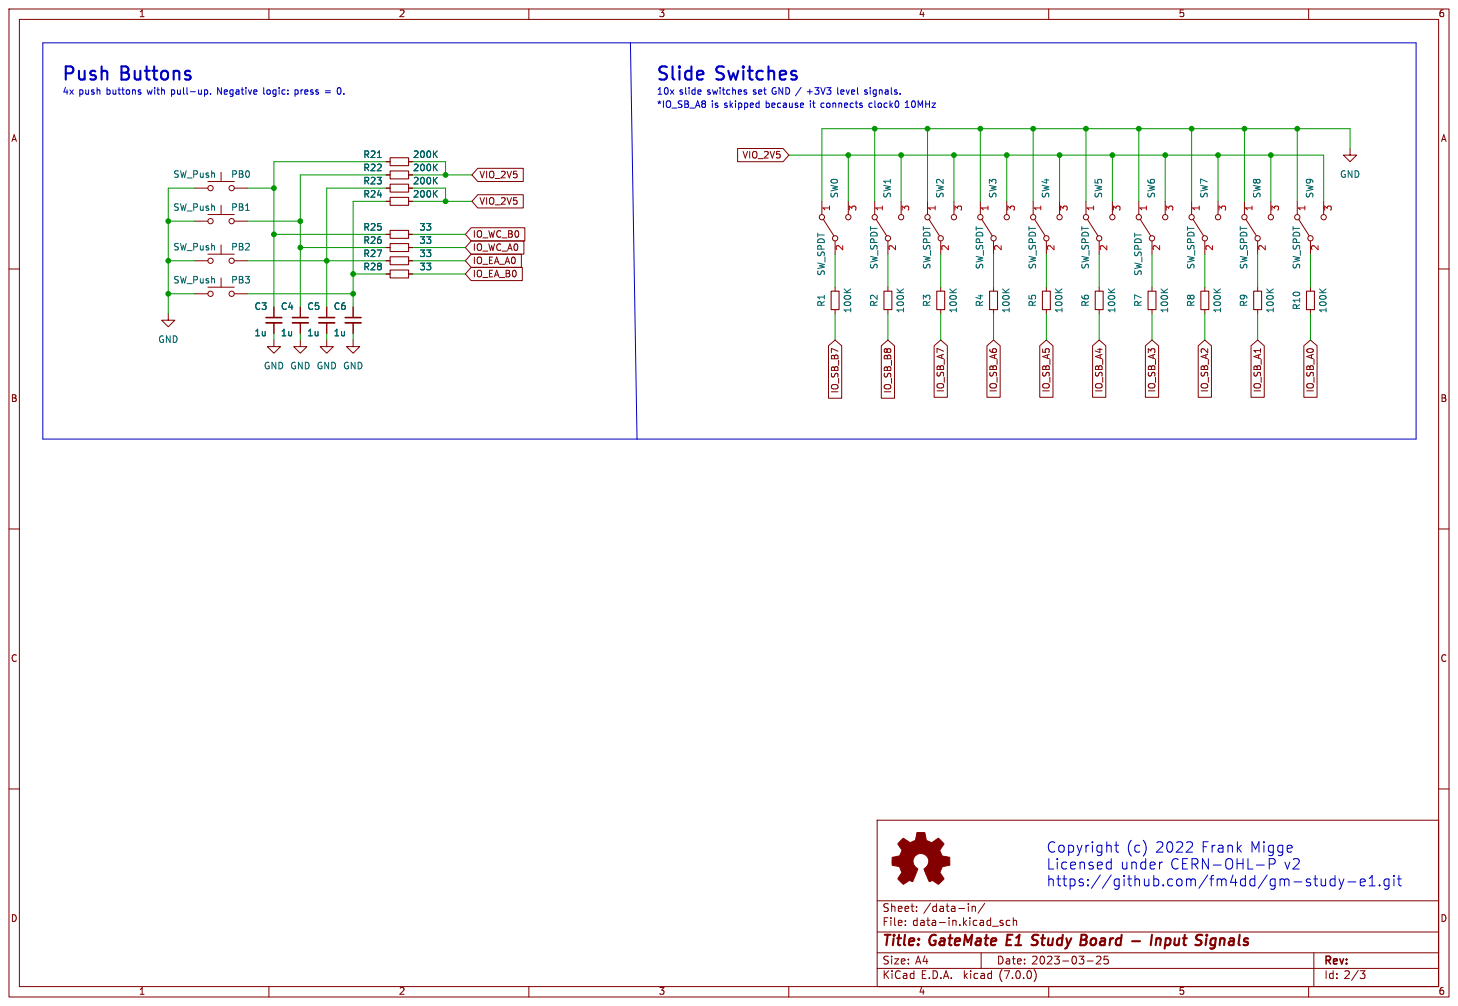
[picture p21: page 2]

10x slide switches set GND / +3V3 level signals.

Copyright (c) 2022 Frank Migge
https://github.com/fm4dd/gm-study-e1.git

File: data-in.kicad_sch Sheet: /data-in/
Id: 2/3 Title: GateMate E1 Study Board - Input Signals

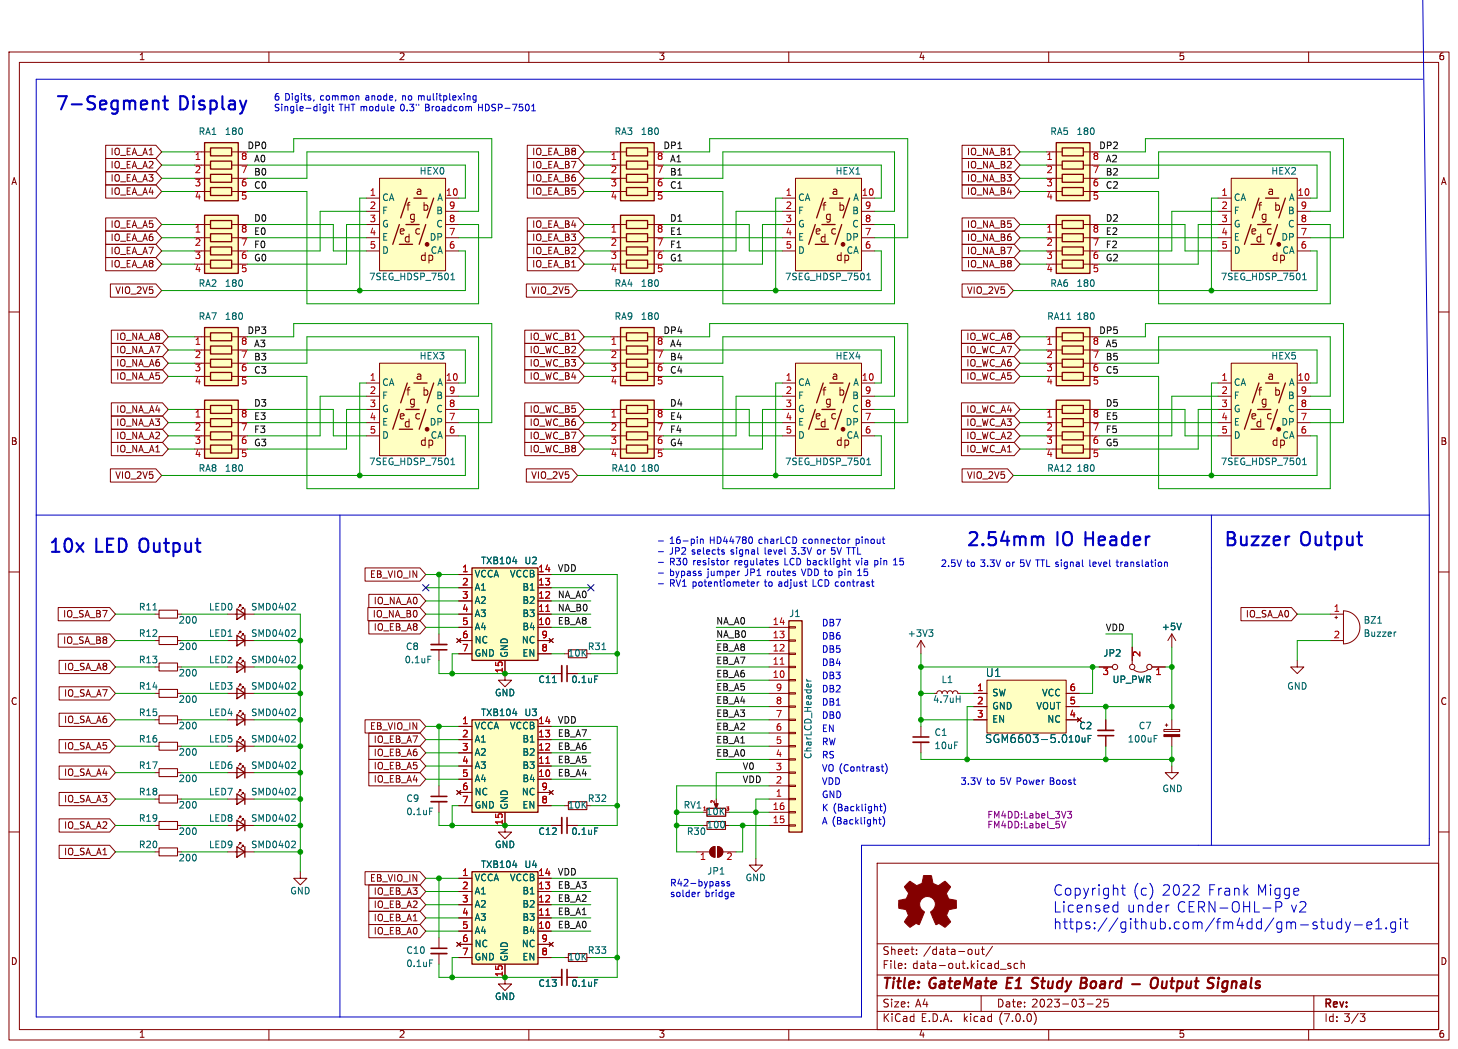
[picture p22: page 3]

- bypass jumper JP1 routes VDD to pin 15

3.3V to 5V Power Boost DB6 K (Backlight)

Id: 3/3 Title: GateMate E1 Study Board - Output Signals

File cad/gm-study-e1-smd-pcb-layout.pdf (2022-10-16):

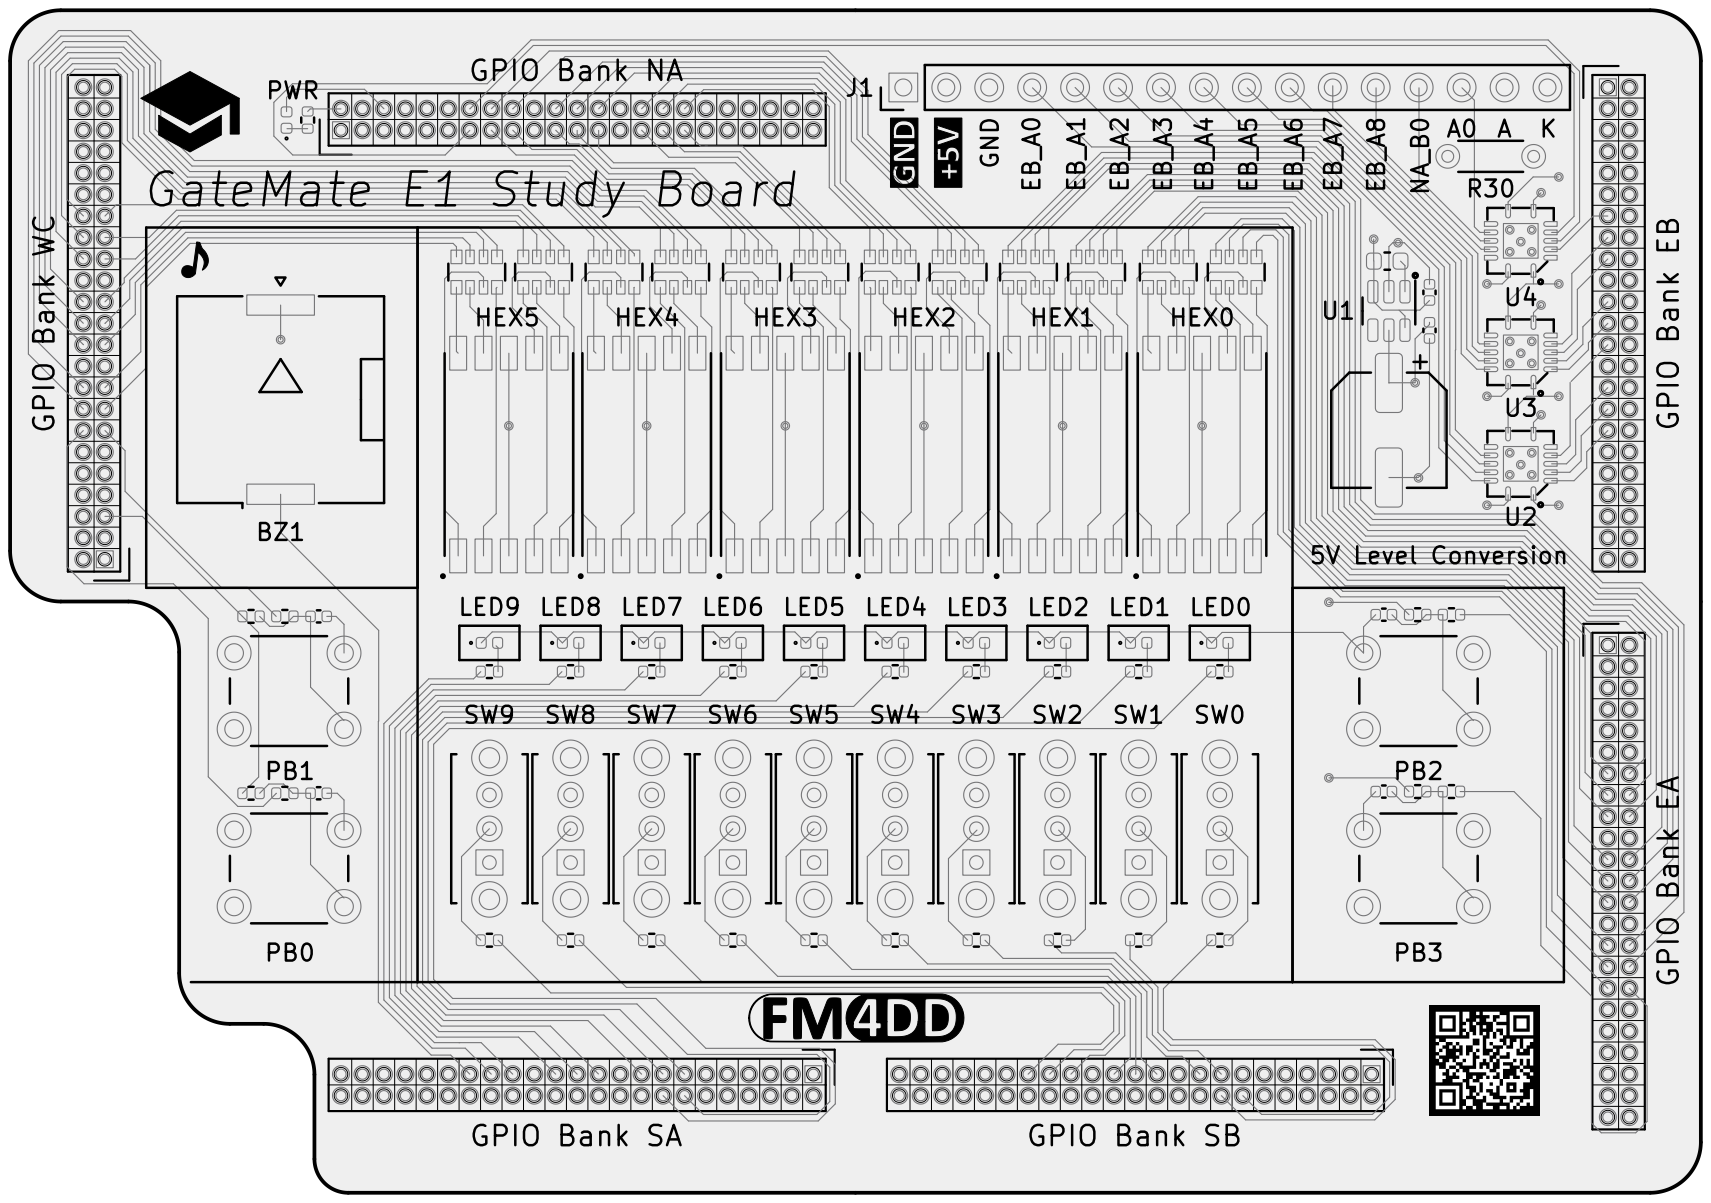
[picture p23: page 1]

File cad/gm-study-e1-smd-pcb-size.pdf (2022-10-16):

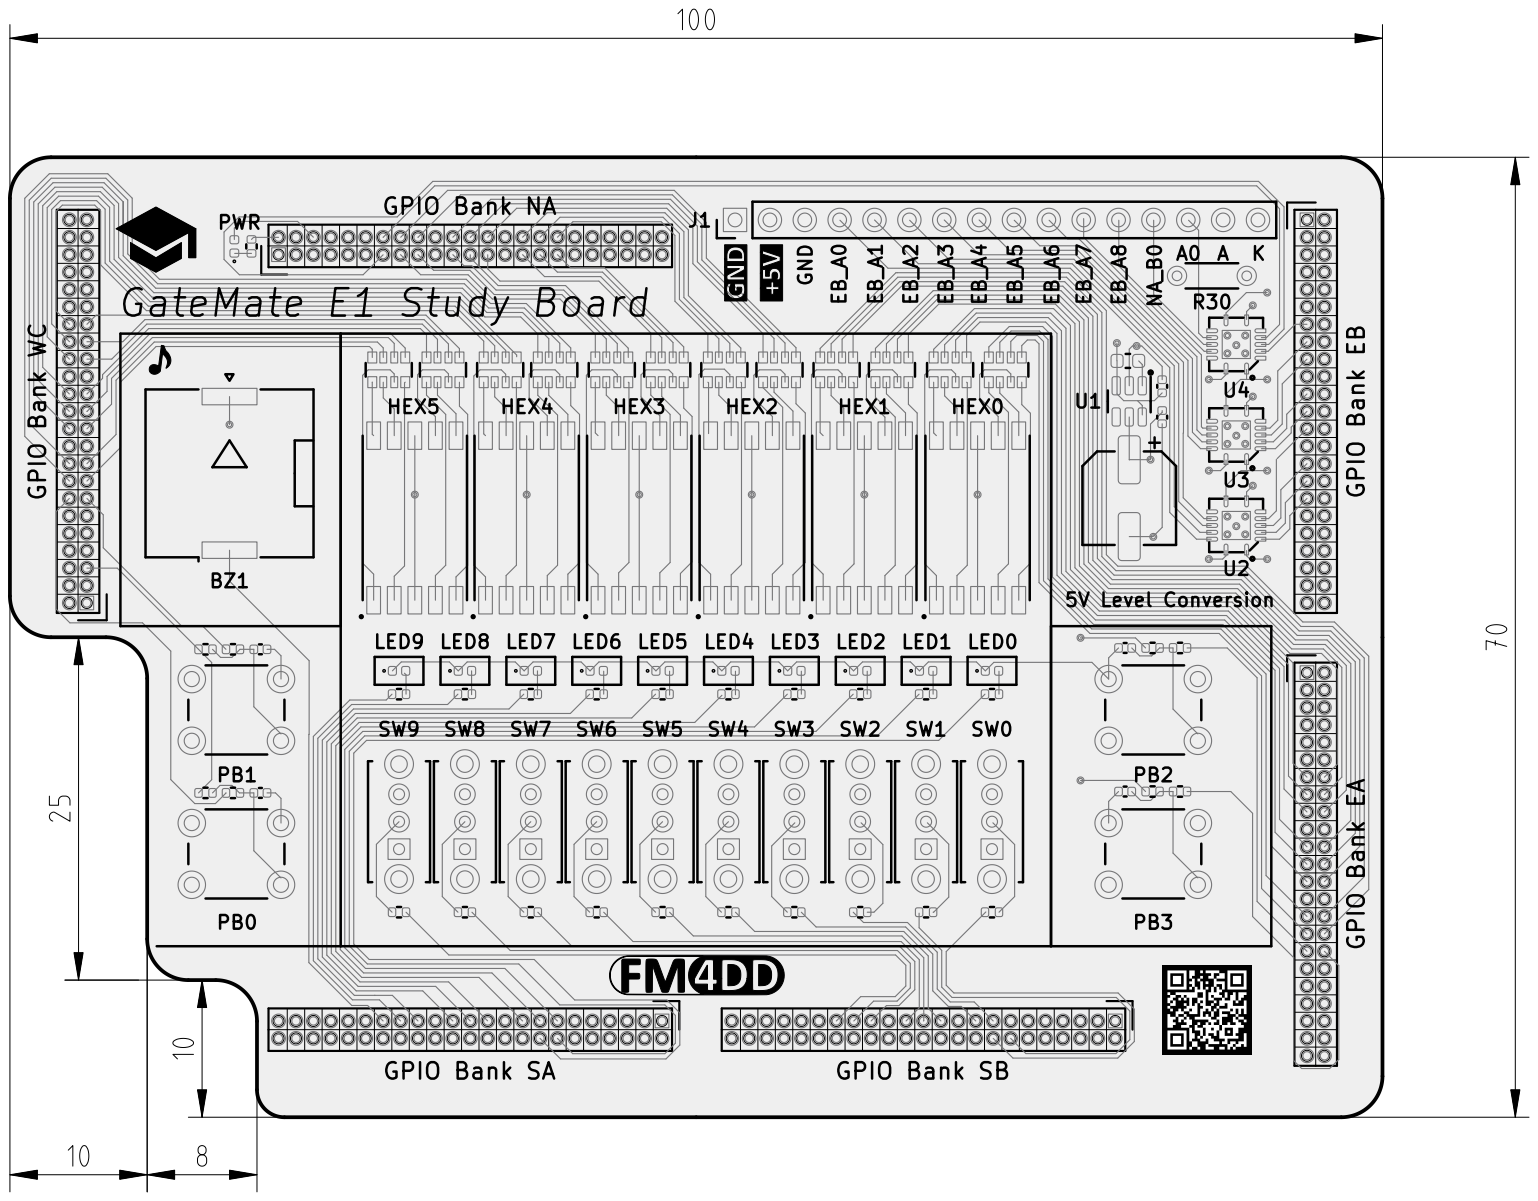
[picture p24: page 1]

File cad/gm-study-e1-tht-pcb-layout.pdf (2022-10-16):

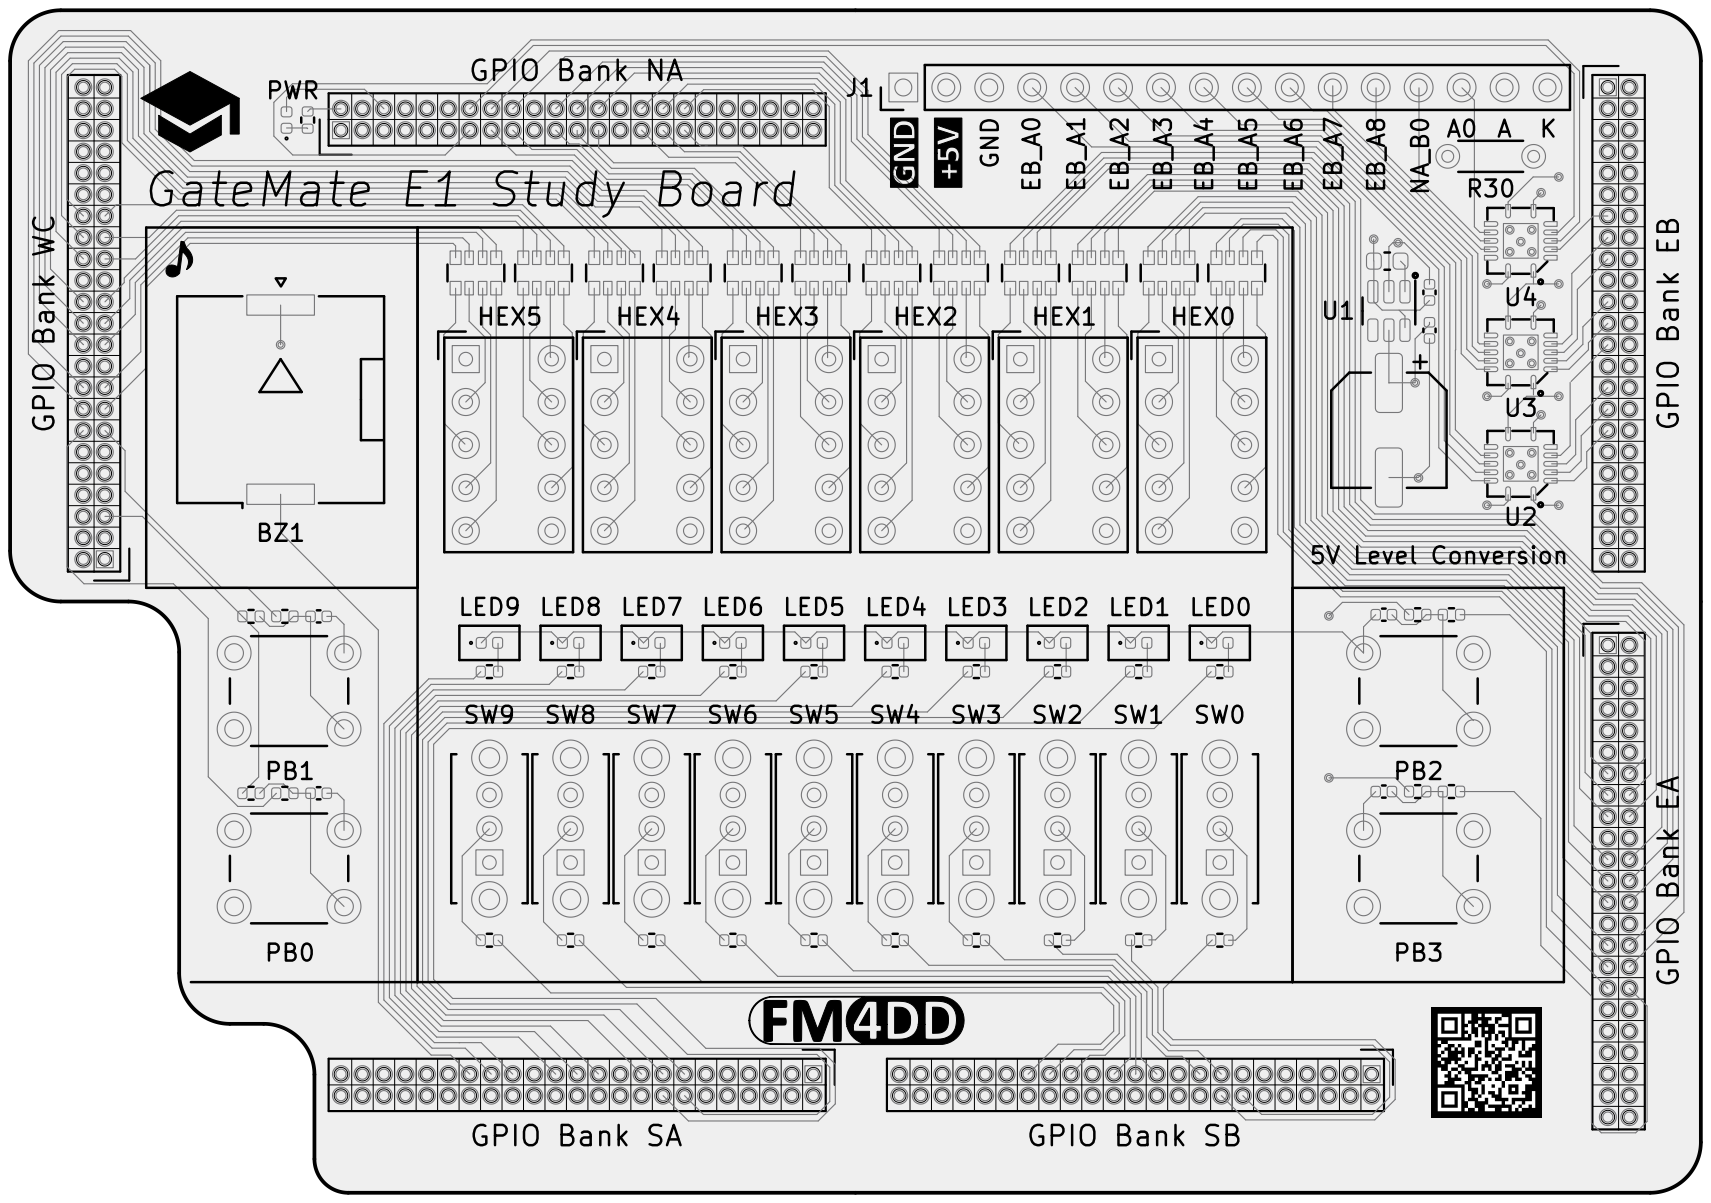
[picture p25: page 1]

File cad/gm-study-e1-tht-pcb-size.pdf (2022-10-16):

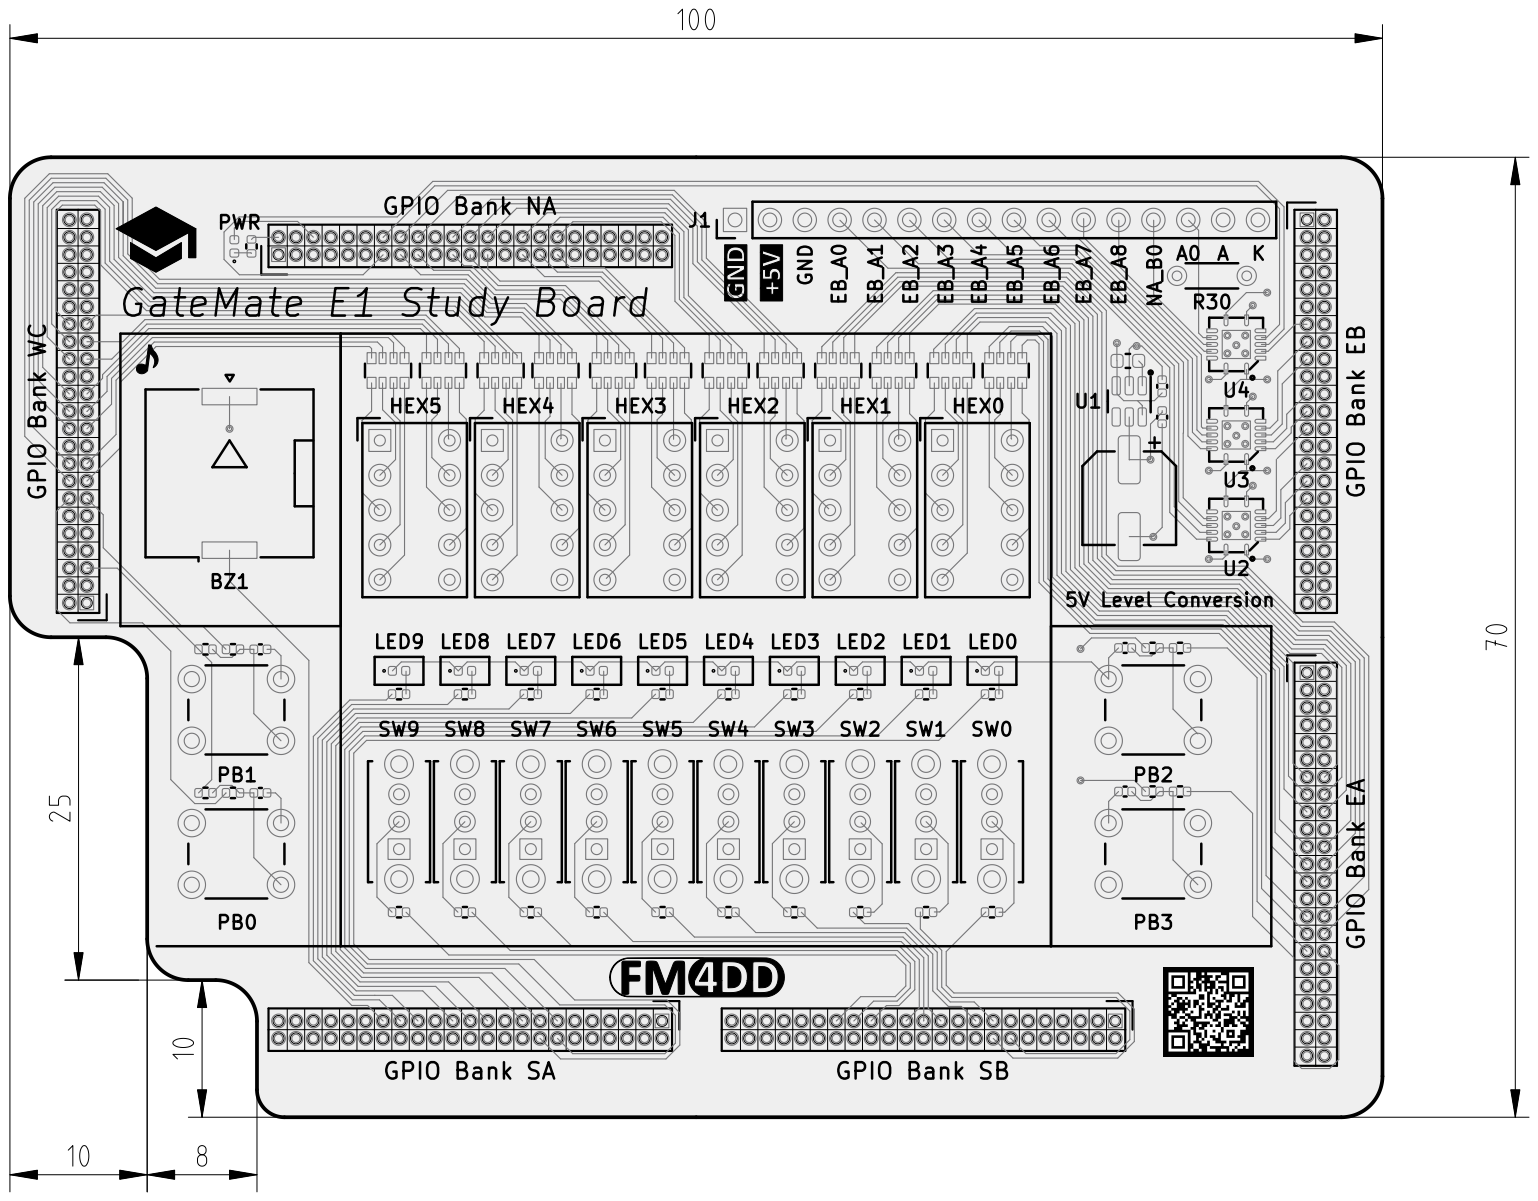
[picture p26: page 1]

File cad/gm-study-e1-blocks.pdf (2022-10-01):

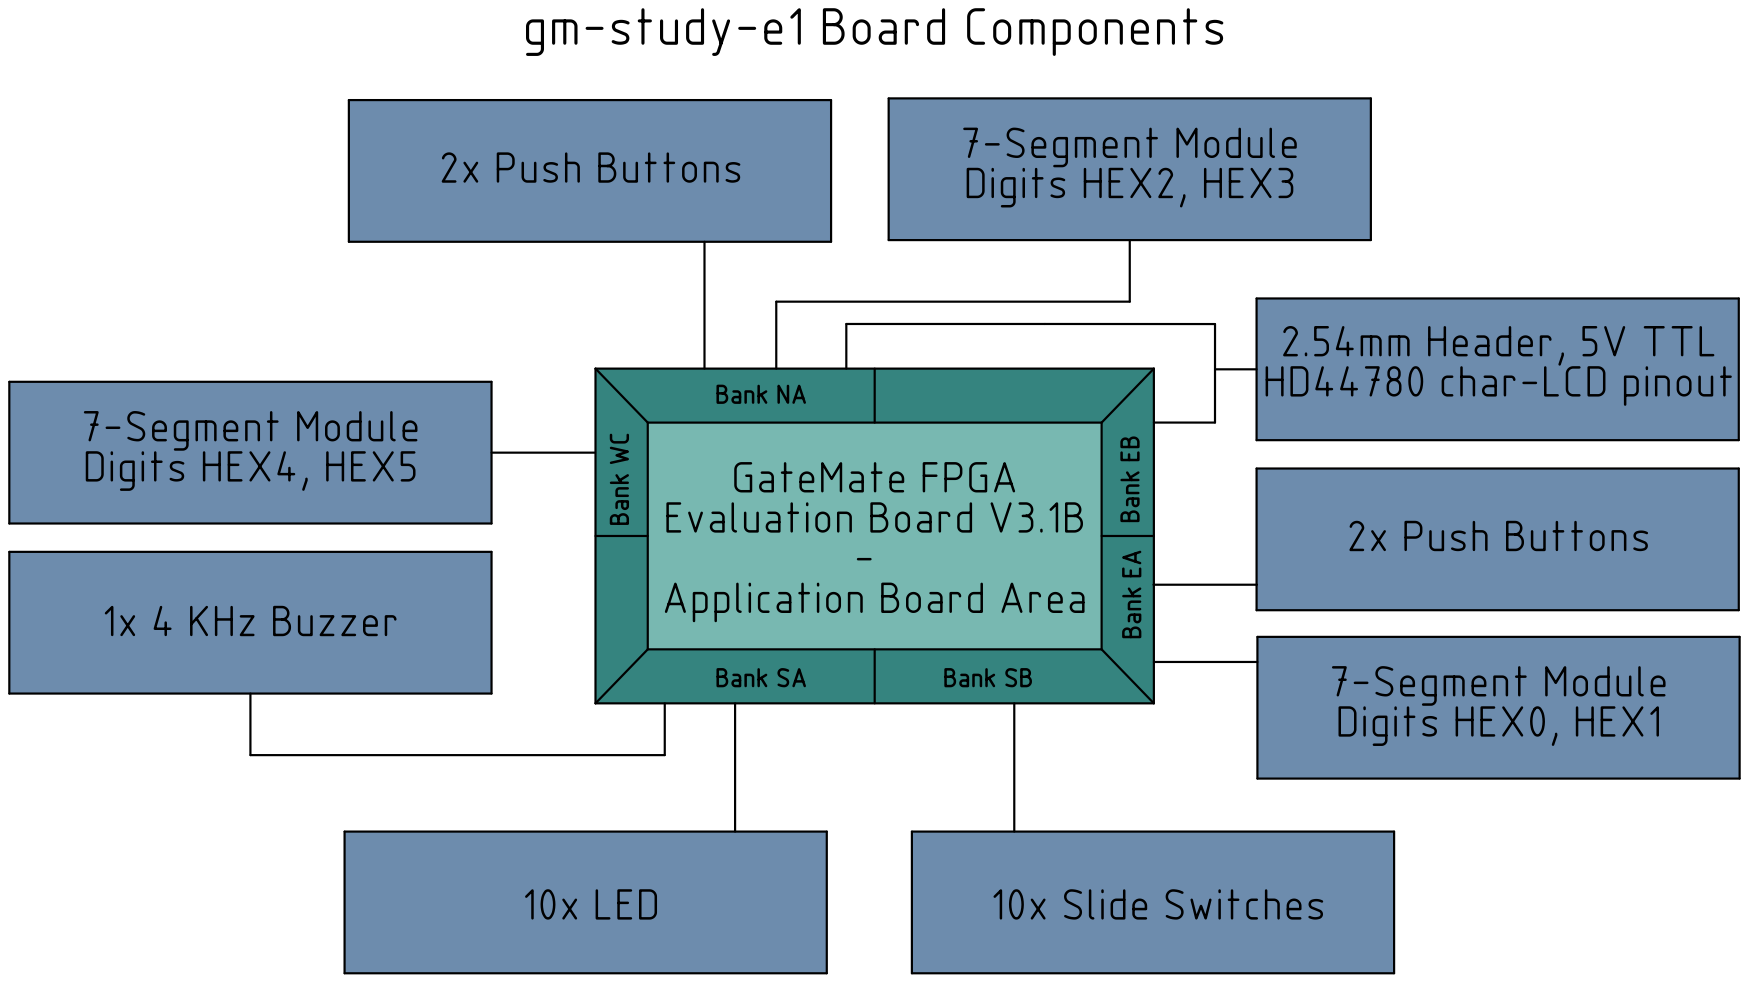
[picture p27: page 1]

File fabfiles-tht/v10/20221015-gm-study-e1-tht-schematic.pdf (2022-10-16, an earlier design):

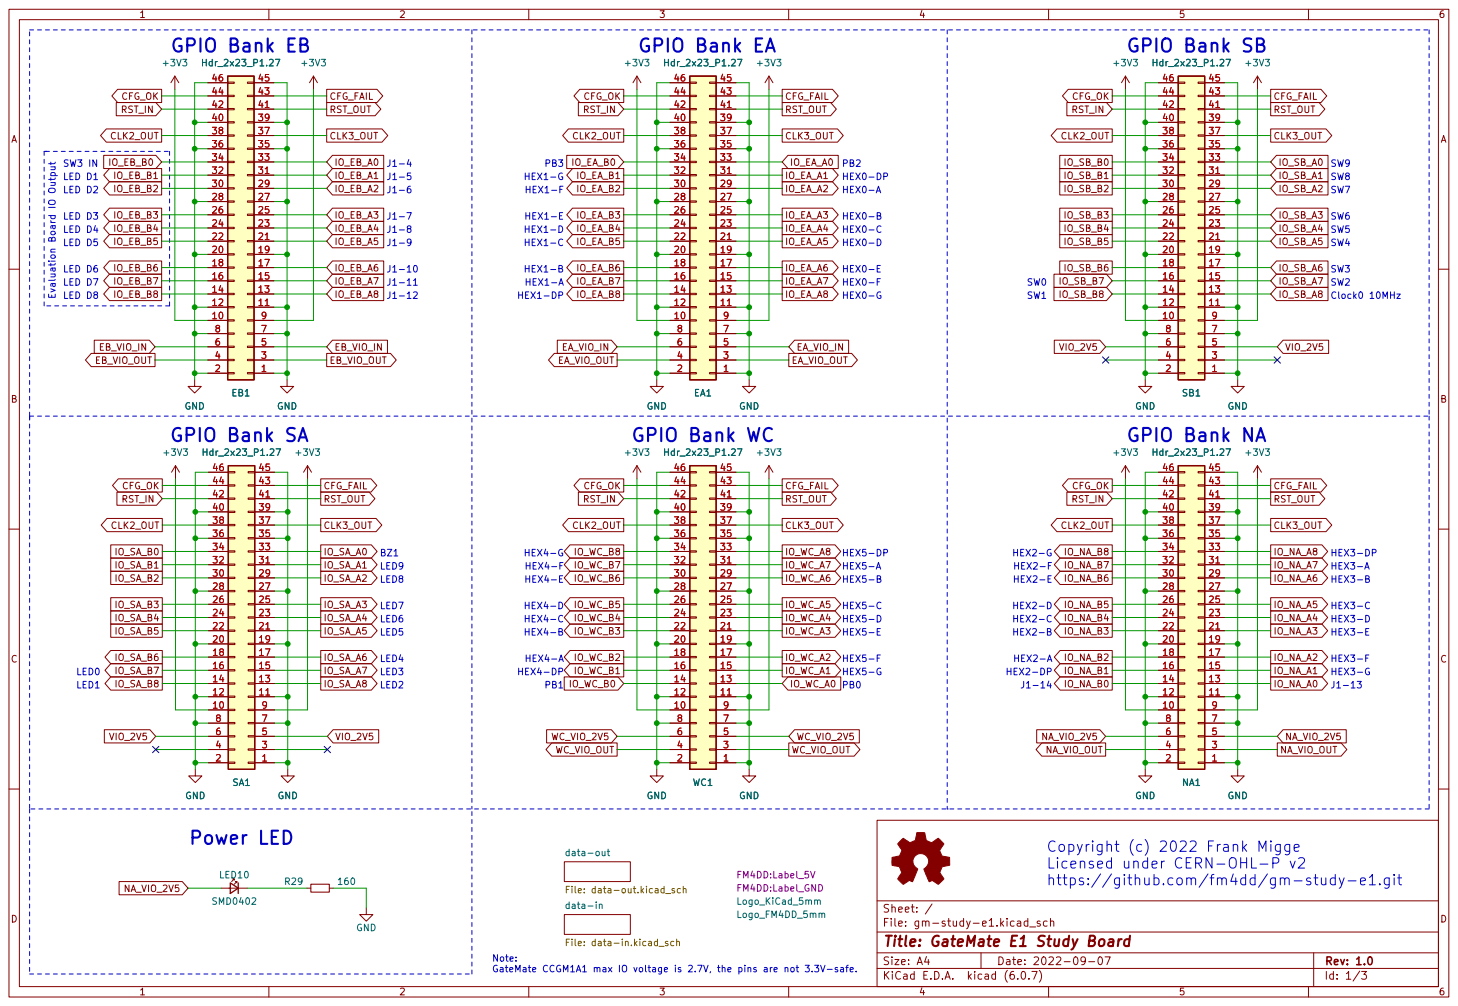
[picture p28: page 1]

SW7 HEX3-DP GPIO Bank SB
IO_SB_B6 RST_IN

data-out File: data-out.kicad_sch GND

PB1 HEX4-A Note: GateMate CCGM1A1 max IO voltage is 2.7V, the pins are not 3.3V-safe. BZ1
LED9
LED8

Licensed under CERN-OHL-P v2
https://github.com/fm4dd/gm-study-e1.git

File: gm-study-e1.kicad_sch Sheet: / data-in File: data-in.kicad_sch

Id: 1/3 Title: GateMate E1 Study Board


4x push buttons with pull-up. Negative logic: press = 0.

10x slide switches set GND / +3V3 level signals.

Copyright (c) 2022 Frank Migge
Licensed under CERN-OHL-P v2
https://github.com/fm4dd/gm-study-e1.git

Id: 2/3 Title: GateMate E1 Study Board - Input Signals


6 Digits, common anode, no mulitplexing
Single-digit THT module 0.3" Broadcom HDSP-7501

https://github.com/fm4dd/gm-study-e1.git 3.3V to 5V Power Boost 10x LED Output

16-pin HD44780 character LCD connector compatible, with level shifter to 5V TTL
Adding R30 powers LCD backlight via pin 15, leave open to disable LCD backlight C2

Licensed under CERN-OHL-P v2

Id: 3/3 Title: GateMate E1 Study Board - Output Signals

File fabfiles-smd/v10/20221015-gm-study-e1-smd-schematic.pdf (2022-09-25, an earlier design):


SW7 HEX3-DP GPIO Bank SB
IO_SB_B6 RST_IN

data-out File: data-out.kicad_sch GND

PB1 HEX4-A Note: GateMate CCGM1A1 max IO voltage is 2.7V, the pins are not 3.3V-safe. BZ1
LED9
LED8

Licensed under CERN-OHL-P v2
https://github.com/fm4dd/gm-study-e1.git

File: gm-study-e1.kicad_sch Sheet: / data-in File: data-in.kicad_sch

Id: 1/3 Title: GateMate E1 Study Board


4x push buttons with pull-up. Negative logic: press = 0.

10x slide switches set GND / +3V3 level signals.
*IO_SB_A8 is skipped because it connects clock0 10MHz

Copyright (c) 2022 Frank Migge
Licensed under CERN-OHL-P v2
https://github.com/fm4dd/gm-study-e1.git

File: data-in.kicad_sch Sheet: /data-in/
Id: 2/3 Title: GateMate E1 Study Board - Input Signals


16-pin HD44780 character LCD connector compatible, with level shifter to 5V TTL
Adding R30 powers LCD backlight via pin 15, leave open to disable LCD backlight

Licensed under CERN-OHL-P v2
https://github.com/fm4dd/gm-study-e1.git

File: data-out.kicad_sch Sheet: /data-out/ R20

Id: 3/3 Title: GateMate E1 Study Board - Output Signals

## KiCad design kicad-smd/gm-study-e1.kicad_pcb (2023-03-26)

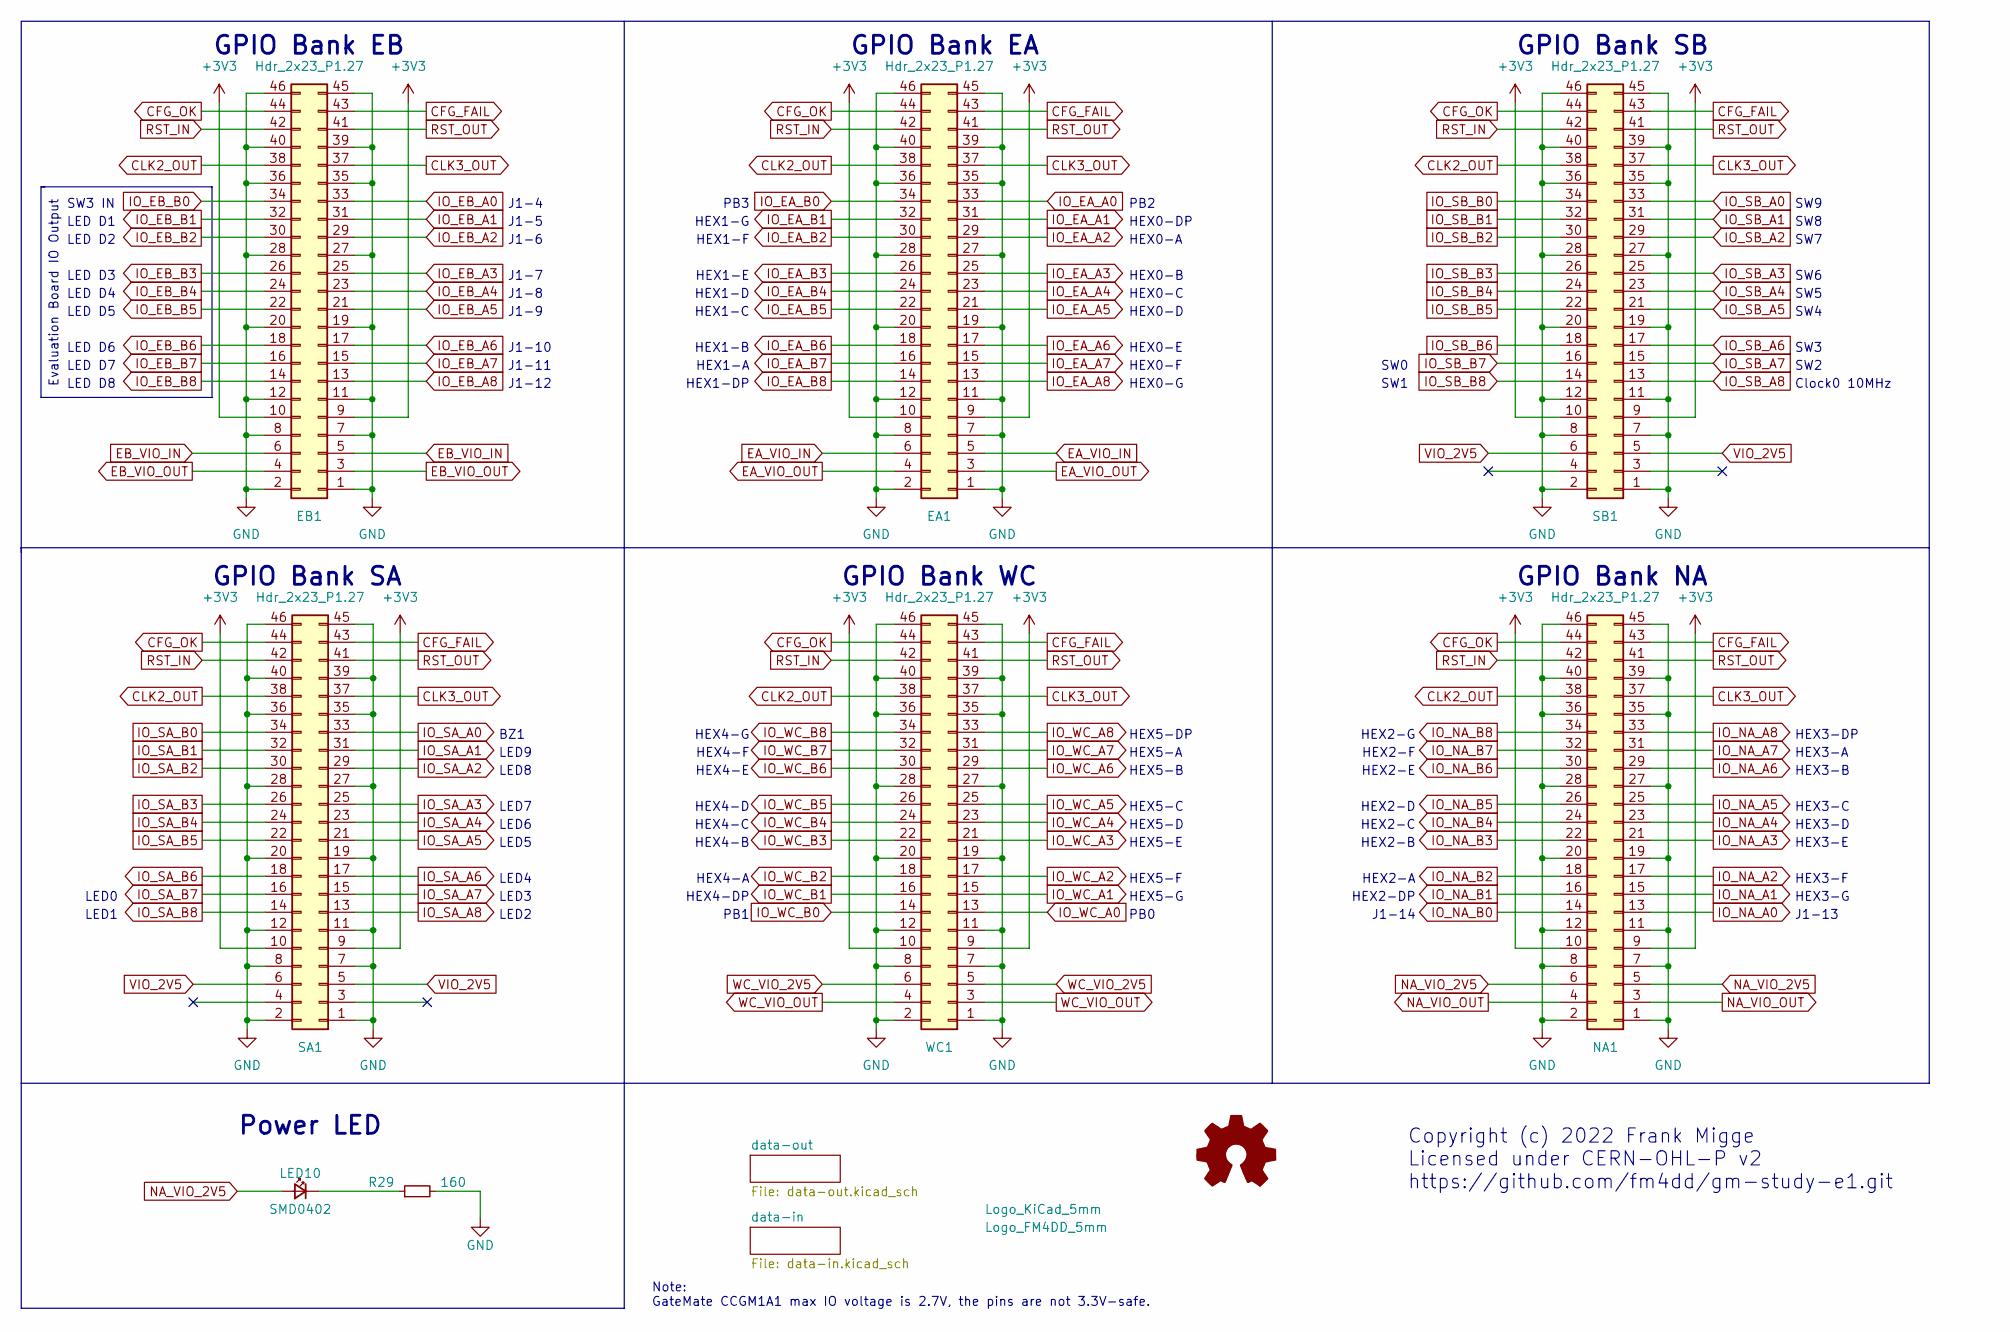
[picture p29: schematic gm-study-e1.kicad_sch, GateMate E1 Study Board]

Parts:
EA1: Hdr_2x23_P1.27; PinHeader_2x23_P1.27_backside
EB1: Hdr_2x23_P1.27; PinHeader_2x23_P1.27_backside
LB1: Logo_KiCad_5mm; Logo_KiCad_5mm_SScr
LB2: Label_5V
LB3: Label_GND
LB4: Logo_FM4DD_5mm; Logo_FM4DD_5mm_SScr
LED10: SMD0402; LED_0402_no_frame
NA1: Hdr_2x23_P1.27; PinHeader_2x23_P1.27_backside
R29: 160; R_0402_1005Metric
SA1: Hdr_2x23_P1.27; PinHeader_2x23_P1.27_backside
SB1: Hdr_2x23_P1.27; PinHeader_2x23_P1.27_backside
WC1: Hdr_2x23_P1.27; PinHeader_2x23_P1.27_backside

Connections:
+3V3: EA1.9, EA1.10, EB1.9, EB1.10, NA1.9, NA1.10, SA1.9, SA1.10, SB1.9, SB1.10, WC1.9, WC1.10; also elsewhere on the board
CFG_FAIL: EA1.43, EB1.43, NA1.43, SA1.43, SB1.43, WC1.43
CFG_OK: EA1.44, EB1.44, NA1.44, SA1.44, SB1.44, WC1.44
CLK2_OUT: EA1.38, EB1.38, NA1.38, SA1.38, SB1.38, WC1.38
CLK3_OUT: EA1.37, EB1.37, NA1.37, SA1.37, SB1.37, WC1.37
EA_VIO_IN: EA1.5, EA1.6
EA_VIO_OUT: EA1.3, EA1.4
EB_VIO_IN: EB1.5, EB1.6; also elsewhere on the board
EB_VIO_OUT: EB1.3, EB1.4
GND: EA1.1, EA1.2, EA1.7, EA1.8, EA1.11, EA1.12, EA1.19, EA1.20, EA1.27, EA1.28, EA1.35, EA1.36, EA1.39, EA1.40, EA1.45, EA1.46, EB1.1, EB1.2, EB1.7, EB1.8, EB1.11, EB1.12, EB1.19, EB1.20, EB1.27, EB1.28, EB1.35, EB1.36, EB1.39, EB1.40, EB1.45, EB1.46, NA1.1, NA1.2, NA1.7, NA1.8, NA1.11, NA1.12, NA1.19, NA1.20, NA1.27, NA1.28, NA1.35, NA1.36, NA1.39, NA1.40, NA1.45, NA1.46, R29.2, SA1.1, SA1.2, SA1.7, SA1.8, SA1.11, SA1.12, SA1.19, SA1.20, SA1.27, SA1.28, SA1.35, SA1.36, SA1.39, SA1.40, SA1.45, SA1.46, SB1.1, SB1.2, SB1.7, SB1.8, SB1.11, SB1.12, SB1.19, SB1.20, SB1.27, SB1.28, SB1.35, SB1.36, SB1.39, SB1.40, SB1.45, SB1.46, WC1.1, WC1.2, WC1.7, WC1.8, WC1.11, WC1.12, WC1.19, WC1.20, WC1.27, WC1.28, WC1.35, WC1.36, WC1.39, WC1.40, WC1.45, WC1.46; also elsewhere on the board
IO_EA_A0: EA1.33; also elsewhere on the board
IO_EA_A1: EA1.31; also elsewhere on the board
IO_EA_A2: EA1.29; also elsewhere on the board
IO_EA_A3: EA1.25; also elsewhere on the board
IO_EA_A4: EA1.23; also elsewhere on the board
IO_EA_A5: EA1.21; also elsewhere on the board
IO_EA_A6: EA1.17; also elsewhere on the board
IO_EA_A7: EA1.15; also elsewhere on the board
IO_EA_A8: EA1.13; also elsewhere on the board
IO_EA_B0: EA1.34; also elsewhere on the board
IO_EA_B1: EA1.32; also elsewhere on the board
IO_EA_B2: EA1.30; also elsewhere on the board
IO_EA_B3: EA1.26; also elsewhere on the board
IO_EA_B4: EA1.24; also elsewhere on the board
IO_EA_B5: EA1.22; also elsewhere on the board
IO_EA_B6: EA1.18; also elsewhere on the board
IO_EA_B7: EA1.16; also elsewhere on the board
IO_EA_B8: EA1.14; also elsewhere on the board
IO_EB_A0: EB1.33; also elsewhere on the board
IO_EB_A1: EB1.31; also elsewhere on the board
IO_EB_A2: EB1.29; also elsewhere on the board
IO_EB_A3: EB1.25; also elsewhere on the board
IO_EB_A4: EB1.23; also elsewhere on the board
IO_EB_A5: EB1.21; also elsewhere on the board
IO_EB_A6: EB1.17; also elsewhere on the board
IO_EB_A7: EB1.15; also elsewhere on the board
IO_EB_A8: EB1.13; also elsewhere on the board
IO_EB_B0: EB1.34
IO_EB_B1: EB1.32
IO_EB_B2: EB1.30
IO_EB_B3: EB1.26
IO_EB_B4: EB1.24
IO_EB_B5: EB1.22
IO_EB_B6: EB1.18
IO_EB_B7: EB1.16
IO_EB_B8: EB1.14
IO_NA_A0: NA1.13; also elsewhere on the board
IO_NA_A1: NA1.15; also elsewhere on the board
IO_NA_A2: NA1.17; also elsewhere on the board
IO_NA_A3: NA1.21; also elsewhere on the board
IO_NA_A4: NA1.23; also elsewhere on the board
IO_NA_A5: NA1.25; also elsewhere on the board
IO_NA_A6: NA1.29; also elsewhere on the board
IO_NA_A7: NA1.31; also elsewhere on the board
IO_NA_A8: NA1.33; also elsewhere on the board
IO_NA_B0: NA1.14; also elsewhere on the board
IO_NA_B1: NA1.16; also elsewhere on the board
IO_NA_B2: NA1.18; also elsewhere on the board
IO_NA_B3: NA1.22; also elsewhere on the board
IO_NA_B4: NA1.24; also elsewhere on the board
IO_NA_B5: NA1.26; also elsewhere on the board
IO_NA_B6: NA1.30; also elsewhere on the board
IO_NA_B7: NA1.32; also elsewhere on the board
IO_NA_B8: NA1.34; also elsewhere on the board
IO_SA_A0: SA1.33; also elsewhere on the board
IO_SA_A1: SA1.31; also elsewhere on the board
IO_SA_A2: SA1.29; also elsewhere on the board
IO_SA_A3: SA1.25; also elsewhere on the board
IO_SA_A4: SA1.23; also elsewhere on the board
IO_SA_A5: SA1.21; also elsewhere on the board
IO_SA_A6: SA1.17; also elsewhere on the board
IO_SA_A7: SA1.15; also elsewhere on the board
IO_SA_A8: SA1.13; also elsewhere on the board
IO_SA_B0: SA1.34
IO_SA_B1: SA1.32
IO_SA_B2: SA1.30
IO_SA_B3: SA1.26
IO_SA_B4: SA1.24
IO_SA_B5: SA1.22
IO_SA_B6: SA1.18
IO_SA_B7: SA1.16; also elsewhere on the board
IO_SA_B8: SA1.14; also elsewhere on the board
IO_SB_A0: SB1.33; also elsewhere on the board
IO_SB_A1: SB1.31; also elsewhere on the board
IO_SB_A2: SB1.29; also elsewhere on the board
IO_SB_A3: SB1.25; also elsewhere on the board
IO_SB_A4: SB1.23; also elsewhere on the board
IO_SB_A5: SB1.21; also elsewhere on the board
IO_SB_A6: SB1.17; also elsewhere on the board
IO_SB_A7: SB1.15; also elsewhere on the board
IO_SB_A8: SB1.13
IO_SB_B0: SB1.34
IO_SB_B1: SB1.32
IO_SB_B2: SB1.30
IO_SB_B3: SB1.26
IO_SB_B4: SB1.24
IO_SB_B5: SB1.22
IO_SB_B6: SB1.18
IO_SB_B7: SB1.16; also elsewhere on the board
IO_SB_B8: SB1.14; also elsewhere on the board
IO_WC_A0: WC1.13; also elsewhere on the board
IO_WC_A1: WC1.15; also elsewhere on the board
IO_WC_A2: WC1.17; also elsewhere on the board
IO_WC_A3: WC1.21; also elsewhere on the board
IO_WC_A4: WC1.23; also elsewhere on the board
IO_WC_A5: WC1.25; also elsewhere on the board
IO_WC_A6: WC1.29; also elsewhere on the board
IO_WC_A7: WC1.31; also elsewhere on the board
IO_WC_A8: WC1.33; also elsewhere on the board
IO_WC_B0: WC1.14; also elsewhere on the board
IO_WC_B1: WC1.16; also elsewhere on the board
IO_WC_B2: WC1.18; also elsewhere on the board
IO_WC_B3: WC1.22; also elsewhere on the board
IO_WC_B4: WC1.24; also elsewhere on the board
IO_WC_B5: WC1.26; also elsewhere on the board
IO_WC_B6: WC1.30; also elsewhere on the board
IO_WC_B7: WC1.32; also elsewhere on the board
IO_WC_B8: WC1.34; also elsewhere on the board
NA_VIO_2V5: LED10.2 (A), NA1.5, NA1.6
NA_VIO_OUT: NA1.3, NA1.4
unnamed: LED10.1 (K), R29.1
RST_IN: EA1.42, EB1.42, NA1.42, SA1.42, SB1.42, WC1.42
RST_OUT: EA1.41, EB1.41, NA1.41, SA1.41, SB1.41, WC1.41
VIO_2V5: SA1.5, SA1.6, SB1.5, SB1.6; also elsewhere on the board
WC_VIO_2V5: WC1.5, WC1.6
WC_VIO_OUT: WC1.3, WC1.4

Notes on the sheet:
HEX1-A
BZ1
SW3
PB0
LED7
HEX5-C
SW7
HEX1-B
HEX1-E
LED D3
Note: GateMate CCGM1A1 max IO voltage is 2.7V, the pins are not 3.3V-safe.
LED D7
HEX3-B
SW4
LED D2
SW8
HEX0-F
J1-7
HEX5-A
J1-10
HEX4-D
HEX5-E
SW3 IN
HEX4-F
HEX1-F
SW0
SW1
LED D8
HEX3-C
Clock0 10MHz
LED D4
HEX3-DP
SW6
HEX0-G
J1-6
HEX2-DP
GPIO Bank NA
LED0
Evaluation Board IO Output
HEX3-A

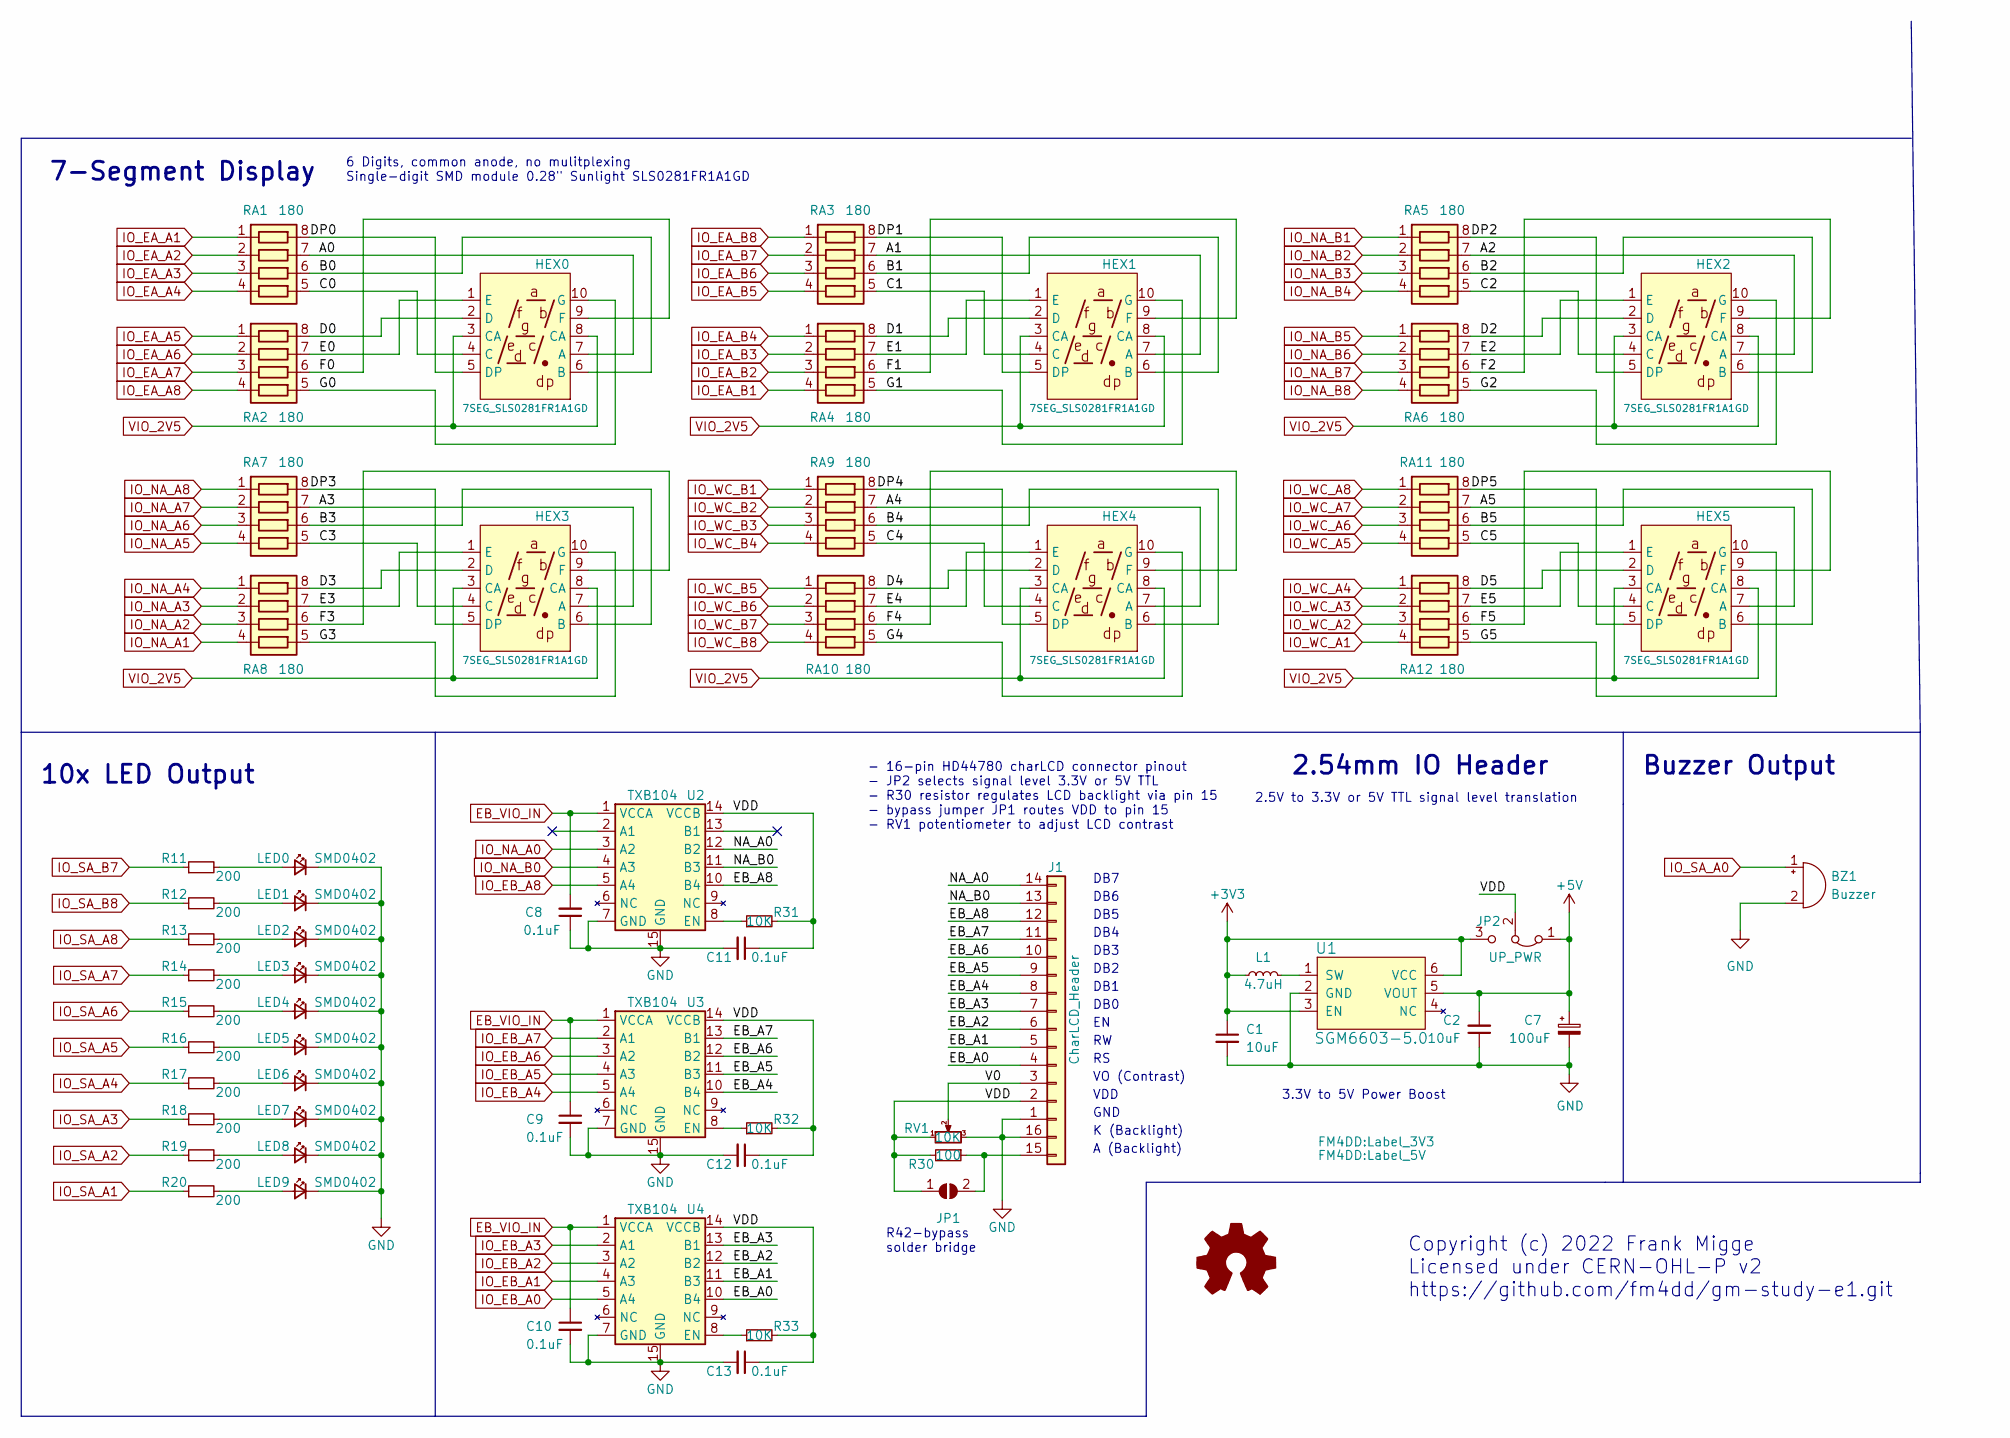
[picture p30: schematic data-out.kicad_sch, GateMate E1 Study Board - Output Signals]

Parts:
BZ1: Buzzer; Buzzer_Murata_PKLCS1212E
C1, C2: 10uF; C_0402_1005Metric
C7: 100uF; CP_Elec_6.3x5.3
C8, C9, C10, C11, C12, C13: 0.1uF; C_0402_1005Metric
HEX0, HEX1, HEX2, HEX3, HEX4, HEX5: 7SEG_SLS0281FR1A1GD; 7SEG SMD SLS0281FR1A1GD
J1: CharLCD_Header; CharLCD Header
JP1: SolderJumper_2_Open; SolderJumper-2_P1.3mm_Open_Pad1.0x1.5mm
JP2: UP_PWR; PinHeader_1x03_P2.54mm_Vertical
L1: 4.7uH; L_0603_1608Metric
LB5: Label_3V3
LB6: Label_5V
LED0, LED1, LED2, LED3, LED4, LED5, LED6, LED7, LED8, LED9: SMD0402; LED_0402_FPGA
R11, R12, R13, R14, R15, R16, R17, R18, R19, R20: 200; R_0402_1005Metric
R30: 100; R_0402_1005Metric
R31, R32, R33: 10K; R_0402_1005Metric
RA1, RA2, RA3, RA4, RA5, RA6, RA7, RA8, RA9, RA10, RA11, RA12: 180; R_Array_Convex_4x0603
RV1: 10K; Potentiometer_Bourns_3362P_Vertical
U1: SGM6603-5.0; SOT-23-6
U2, U3, U4: TXB104; S-PVQFN-N14-1EP_3.65x3.65_P0.5_EP2.05x2.05

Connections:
+3V3: C1.1, JP2.3 (B), L1.1, U1.3 (EN), U1.6 (VCC); also elsewhere on the board
+5V: C2.2, C7.1, JP2.1 (A), U1.5 (VOUT)
/data-out/A0: HEX0.7 (A), RA1.7 (R2)
/data-out/A1: HEX1.7 (A), RA3.7 (R2)
/data-out/A2: HEX2.7 (A), RA5.7 (R2)
/data-out/A3: HEX3.7 (A), RA7.7 (R2)
/data-out/A4: HEX4.7 (A), RA9.7 (R2)
/data-out/A5: HEX5.7 (A), RA11.7 (R2)
/data-out/B0: HEX0.6 (B), RA1.6 (R3)
/data-out/B1: HEX1.6 (B), RA3.6 (R3)
/data-out/B2: HEX2.6 (B), RA5.6 (R3)
/data-out/B3: HEX3.6 (B), RA7.6 (R3)
/data-out/B4: HEX4.6 (B), RA9.6 (R3)
/data-out/B5: HEX5.6 (B), RA11.6 (R3)
/data-out/C0: HEX0.4 (C), RA1.5 (R4)
/data-out/C1: HEX1.4 (C), RA3.5 (R4)
/data-out/C2: HEX2.4 (C), RA5.5 (R4)
/data-out/C3: HEX3.4 (C), RA7.5 (R4)
/data-out/C4: HEX4.4 (C), RA9.5 (R4)
/data-out/C5: HEX5.4 (C), RA11.5 (R4)
/data-out/D0: HEX0.2 (D), RA2.8 (R1)
/data-out/D1: HEX1.2 (D), RA4.8 (R1)
/data-out/D2: HEX2.2 (D), RA6.8 (R1)
/data-out/D3: HEX3.2 (D), RA8.8 (R1)
/data-out/D4: HEX4.2 (D), RA10.8 (R1)
/data-out/D5: HEX5.2 (D), RA12.8 (R1)
/data-out/DP0: HEX0.5 (DP), RA1.8 (R1)
/data-out/DP1: HEX1.5 (DP), RA3.8 (R1)
/data-out/DP2: HEX2.5 (DP), RA5.8 (R1)
/data-out/DP3: HEX3.5 (DP), RA7.8 (R1)
/data-out/DP4: HEX4.5 (DP), RA9.8 (R1)
/data-out/DP5: HEX5.5 (DP), RA11.8 (R1)
/data-out/E0: HEX0.1 (E), RA2.7 (R2)
/data-out/E1: HEX1.1 (E), RA4.7 (R2)
/data-out/E2: HEX2.1 (E), RA6.7 (R2)
/data-out/E3: HEX3.1 (E), RA8.7 (R2)
/data-out/E4: HEX4.1 (E), RA10.7 (R2)
/data-out/E5: HEX5.1 (E), RA12.7 (R2)
/data-out/EB_A0: J1.4, U4.10 (B4)
/data-out/EB_A1: J1.5, U4.11 (B3)
/data-out/EB_A2: J1.6, U4.12 (B2)
/data-out/EB_A3: J1.7, U4.13 (B1)
/data-out/EB_A4: J1.8, U3.10 (B4)
/data-out/EB_A5: J1.9, U3.11 (B3)
/data-out/EB_A6: J1.10, U3.12 (B2)
/data-out/EB_A7: J1.11, U3.13 (B1)
/data-out/EB_A8: J1.12, U2.10 (B4)
/data-out/F0: HEX0.9 (F), RA2.6 (R3)
/data-out/F1: HEX1.9 (F), RA4.6 (R3)
/data-out/F2: HEX2.9 (F), RA6.6 (R3)
/data-out/F3: HEX3.9 (F), RA8.6 (R3)
/data-out/F4: HEX4.9 (F), RA10.6 (R3)
/data-out/F5: HEX5.9 (F), RA12.6 (R3)
/data-out/G0: HEX0.10 (G), RA2.5 (R4)
/data-out/G1: HEX1.10 (G), RA4.5 (R4)
/data-out/G2: HEX2.10 (G), RA6.5 (R4)
/data-out/G3: HEX3.10 (G), RA8.5 (R4)
/data-out/G4: HEX4.10 (G), RA10.5 (R4)
/data-out/G5: HEX5.10 (G), RA12.5 (R4)
/data-out/NA_A0: J1.14, U2.12 (B2)
/data-out/NA_B0: J1.13, U2.11 (B3)
/data-out/V0: J1.3, RV1.2
/data-out/VDD: C11.1, C12.1, C13.1, J1.2, JP1.1 (A), JP2.2 (C), R30.2, R31.2, R32.2, R33.2, RV1.1, U2.14 (VCCB), U3.14 (VCCB), U4.14 (VCCB)
EB_VIO_IN: C8.2, C9.1, C10.1, U2.1 (VCCA), U3.1 (VCCA), U4.1 (VCCA); also elsewhere on the board
GND: BZ1.2 (+), C1.2, C2.1, C7.2, C8.1, C9.2, C10.2, C11.2, C12.2, C13.2, J1.1, J1.16, LED0.1 (K), LED1.1 (K), LED2.1 (K), LED3.1 (K), LED4.1 (K), LED5.1 (K), LED6.1 (K), LED7.1 (K), LED8.1 (K), LED9.1 (K), RV1.3, U1.2 (GND), U2.7 (GND), U2.15 (GND), U3.7 (GND), U3.15 (GND), U4.7 (GND), U4.15 (GND); also elsewhere on the board
IO_EA_A1: RA1.1 (R1); also elsewhere on the board
IO_EA_A2: RA1.2 (R2); also elsewhere on the board
IO_EA_A3: RA1.3 (R3); also elsewhere on the board
IO_EA_A4: RA1.4 (R4); also elsewhere on the board
IO_EA_A5: RA2.1 (R1); also elsewhere on the board
IO_EA_A6: RA2.2 (R2); also elsewhere on the board
IO_EA_A7: RA2.3 (R3); also elsewhere on the board
IO_EA_A8: RA2.4 (R4); also elsewhere on the board
IO_EA_B1: RA4.4 (R4); also elsewhere on the board
IO_EA_B2: RA4.3 (R3); also elsewhere on the board
IO_EA_B3: RA4.2 (R2); also elsewhere on the board
IO_EA_B4: RA4.1 (R1); also elsewhere on the board
IO_EA_B5: RA3.4 (R4); also elsewhere on the board
IO_EA_B6: RA3.3 (R3); also elsewhere on the board
IO_EA_B7: RA3.2 (R2); also elsewhere on the board
IO_EA_B8: RA3.1 (R1); also elsewhere on the board
IO_EB_A0: U4.5 (A4); also elsewhere on the board
IO_EB_A1: U4.4 (A3); also elsewhere on the board
IO_EB_A2: U4.3 (A2); also elsewhere on the board
IO_EB_A3: U4.2 (A1); also elsewhere on the board
IO_EB_A4: U3.5 (A4); also elsewhere on the board
IO_EB_A5: U3.4 (A3); also elsewhere on the board
IO_EB_A6: U3.3 (A2); also elsewhere on the board
IO_EB_A7: U3.2 (A1); also elsewhere on the board
IO_EB_A8: U2.5 (A4); also elsewhere on the board
IO_NA_A0: U2.3 (A2); also elsewhere on the board
IO_NA_A1: RA8.4 (R4); also elsewhere on the board
IO_NA_A2: RA8.3 (R3); also elsewhere on the board
IO_NA_A3: RA8.2 (R2); also elsewhere on the board
IO_NA_A4: RA8.1 (R1); also elsewhere on the board
IO_NA_A5: RA7.4 (R4); also elsewhere on the board
IO_NA_A6: RA7.3 (R3); also elsewhere on the board
IO_NA_A7: RA7.2 (R2); also elsewhere on the board
IO_NA_A8: RA7.1 (R1); also elsewhere on the board
IO_NA_B0: U2.4 (A3); also elsewhere on the board
IO_NA_B1: RA5.1 (R1); also elsewhere on the board
IO_NA_B2: RA5.2 (R2); also elsewhere on the board
IO_NA_B3: RA5.3 (R3); also elsewhere on the board
IO_NA_B4: RA5.4 (R4); also elsewhere on the board
IO_NA_B5: RA6.1 (R1); also elsewhere on the board
IO_NA_B6: RA6.2 (R2); also elsewhere on the board
IO_NA_B7: RA6.3 (R3); also elsewhere on the board
IO_NA_B8: RA6.4 (R4); also elsewhere on the board
IO_SA_A0: BZ1.1 (-); also elsewhere on the board
IO_SA_A1: R20.1; also elsewhere on the board
IO_SA_A2: R19.1; also elsewhere on the board
IO_SA_A3: R18.1; also elsewhere on the board
IO_SA_A4: R17.1; also elsewhere on the board
IO_SA_A5: R16.1; also elsewhere on the board
IO_SA_A6: R15.1; also elsewhere on the board
IO_SA_A7: R14.1; also elsewhere on the board
IO_SA_A8: R13.1; also elsewhere on the board
IO_SA_B7: R11.1; also elsewhere on the board
IO_SA_B8: R12.1; also elsewhere on the board
IO_WC_A1: RA12.4 (R4); also elsewhere on the board
IO_WC_A2: RA12.3 (R3); also elsewhere on the board
IO_WC_A3: RA12.2 (R2); also elsewhere on the board
IO_WC_A4: RA12.1 (R1); also elsewhere on the board
IO_WC_A5: RA11.4 (R4); also elsewhere on the board
IO_WC_A6: RA11.3 (R3); also elsewhere on the board
IO_WC_A7: RA11.2 (R2); also elsewhere on the board
IO_WC_A8: RA11.1 (R1); also elsewhere on the board
IO_WC_B1: RA9.1 (R1); also elsewhere on the board
IO_WC_B2: RA9.2 (R2); also elsewhere on the board
IO_WC_B3: RA9.3 (R3); also elsewhere on the board
IO_WC_B4: RA9.4 (R4); also elsewhere on the board
IO_WC_B5: RA10.1 (R1); also elsewhere on the board
IO_WC_B6: RA10.2 (R2); also elsewhere on the board
IO_WC_B7: RA10.3 (R3); also elsewhere on the board
IO_WC_B8: RA10.4 (R4); also elsewhere on the board
unnamed: J1.15, JP1.2 (B), R30.1
unnamed: LED0.2 (A), R11.2
unnamed: LED1.2 (A), R12.2
unnamed: LED2.2 (A), R13.2
unnamed: LED3.2 (A), R14.2
unnamed: LED4.2 (A), R15.2
unnamed: LED5.2 (A), R16.2
unnamed: LED6.2 (A), R17.2
unnamed: LED7.2 (A), R18.2
unnamed: LED8.2 (A), R19.2
unnamed: LED9.2 (A), R20.2
unnamed: L1.2, U1.1 (SW)
unnamed: R31.1, U2.8 (EN)
unnamed: R32.1, U3.8 (EN)
unnamed: R33.1, U4.8 (EN)
VIO_2V5: HEX0.3 (CA), HEX0.8 (CA), HEX1.3 (CA), HEX1.8 (CA), HEX2.3 (CA), HEX2.8 (CA), HEX3.3 (CA), HEX3.8 (CA), HEX4.3 (CA), HEX4.8 (CA), HEX5.3 (CA), HEX5.8 (CA); also elsewhere on the board

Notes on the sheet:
10x LED Output
2.54mm IO Header
K (Backlight)
3.3V to 5V Power Boost
DB3
DB0
A (Backlight)
VO (Contrast)
DB7
Copyright (c) 2022 Frank Migge Licensed under CERN-OHL-P v2 https://github.com/fm4dd/gm-study-e1.git
DB1
R42-bypass solder bridge
VDD
2.5V to 3.3V or 5V TTL signal level translation
6 Digits, common anode, no mulitplexing Single-digit SMD module 0.28" Sunlight SLS0281FR1A1GD
GND
DB4
- 16-pin HD44780 charLCD connector pinout - JP2 selects signal level 3.3V or 5V TTL - R30 resistor regulates LCD backlight via pin 15 - bypass jumper JP1 routes VDD to pin 15 - RV1 potentiometer to adjust LCD contrast
DB6
7-Segment Display
DB2
Buzzer Output
DB5

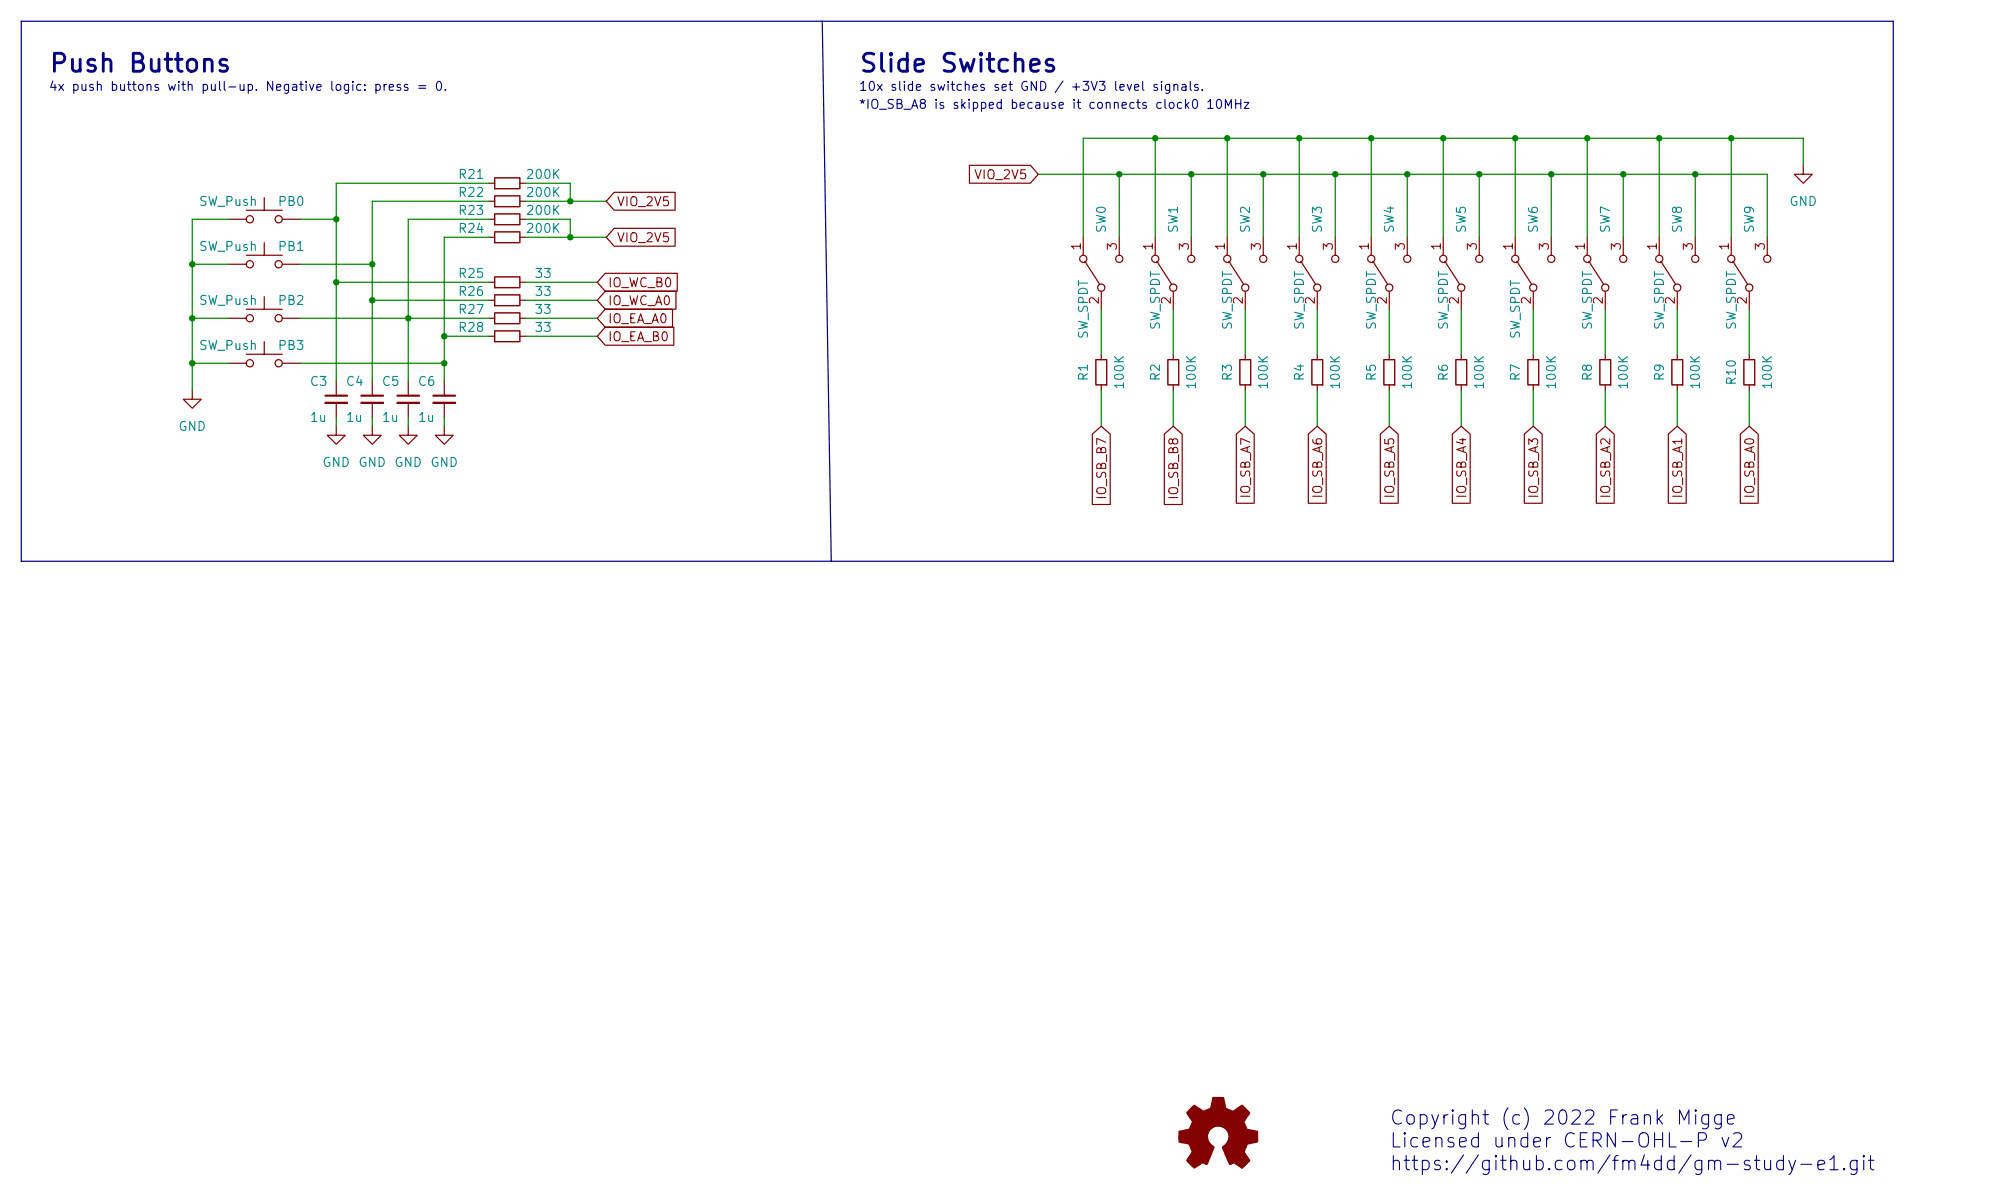
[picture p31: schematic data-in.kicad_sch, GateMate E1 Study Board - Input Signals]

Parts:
C3, C4, C5, C6: 1u; C_0402_1005Metric
PB0, PB1, PB2, PB3: SW_Push; SW_PUSH_6mm
R1, R2, R3, R4, R5, R6, R7, R8, R9, R10: 100K; R_0402_1005Metric
R21, R22, R23, R24: 200K; R_0402_1005Metric
R25, R26, R27, R28: 33; R_0402_1005Metric
SW0, SW1, SW2, SW3, SW4, SW5, SW6, SW7, SW8, SW9: SW_SPDT; SlideSW_SS12-D01

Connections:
GND: C3.2, C4.2, C5.2, C6.2, PB0.1, PB1.1, PB2.1, PB3.1, SW0.1 (A), SW1.1 (A), SW2.1 (A), SW3.1 (A), SW4.1 (A), SW5.1 (A), SW6.1 (A), SW7.1 (A), SW8.1 (A), SW9.1 (A); also elsewhere on the board
IO_EA_A0: R27.2; also elsewhere on the board
IO_EA_B0: R28.2; also elsewhere on the board
IO_SB_A0: R10.1; also elsewhere on the board
IO_SB_A1: R9.1; also elsewhere on the board
IO_SB_A2: R8.1; also elsewhere on the board
IO_SB_A3: R7.1; also elsewhere on the board
IO_SB_A4: R6.1; also elsewhere on the board
IO_SB_A5: R5.1; also elsewhere on the board
IO_SB_A6: R4.1; also elsewhere on the board
IO_SB_A7: R3.1; also elsewhere on the board
IO_SB_B7: R1.1; also elsewhere on the board
IO_SB_B8: R2.1; also elsewhere on the board
IO_WC_A0: R26.2; also elsewhere on the board
IO_WC_B0: R25.2; also elsewhere on the board
unnamed: C3.1, PB0.2, R21.1, R25.1
unnamed: C4.1, PB1.2, R22.1, R26.1
unnamed: C5.1, PB2.2, R23.1, R27.1
unnamed: C6.1, PB3.2, R24.1, R28.1
unnamed: R1.2, SW0.2 (B)
unnamed: R2.2, SW1.2 (B)
unnamed: R3.2, SW2.2 (B)
unnamed: R4.2, SW3.2 (B)
unnamed: R5.2, SW4.2 (B)
unnamed: R6.2, SW5.2 (B)
unnamed: R7.2, SW6.2 (B)
unnamed: R8.2, SW7.2 (B)
unnamed: R9.2, SW8.2 (B)
unnamed: R10.2, SW9.2 (B)
VIO_2V5: R21.2, R22.2, R23.2, R24.2, SW0.3 (C), SW1.3 (C), SW2.3 (C), SW3.3 (C), SW4.3 (C), SW5.3 (C), SW6.3 (C), SW7.3 (C), SW8.3 (C), SW9.3 (C); also elsewhere on the board

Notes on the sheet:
Copyright (c) 2022 Frank Migge Licensed under CERN-OHL-P v2 https://github.com/fm4dd/gm-study-e1.git
4x push buttons with pull-up. Negative logic: press = 0.
Push Buttons
10x slide switches set GND / +3V3 level signals.
Slide Switches
*IO_SB_A8 is skipped because it connects clock0 10MHz

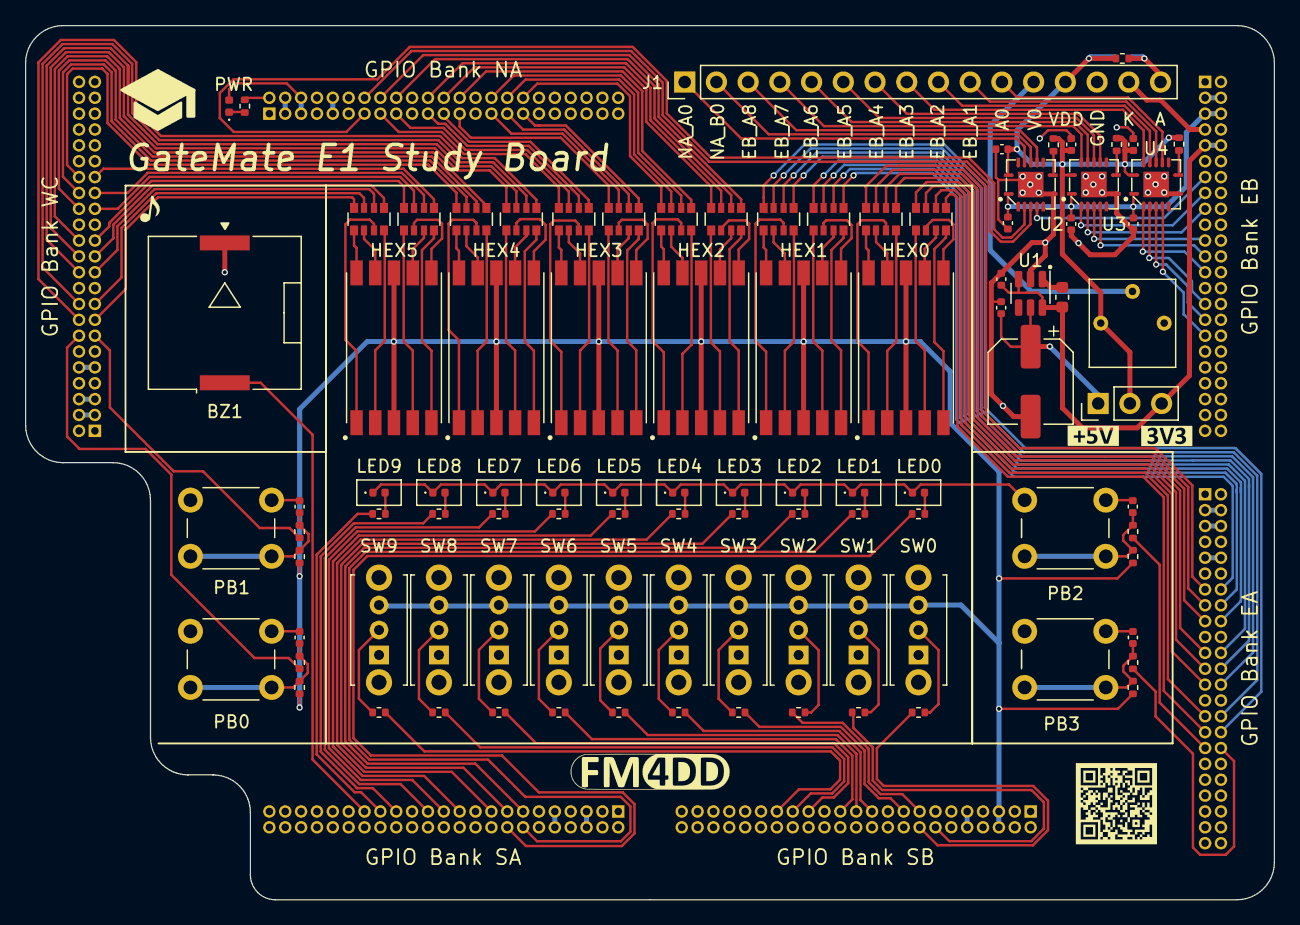
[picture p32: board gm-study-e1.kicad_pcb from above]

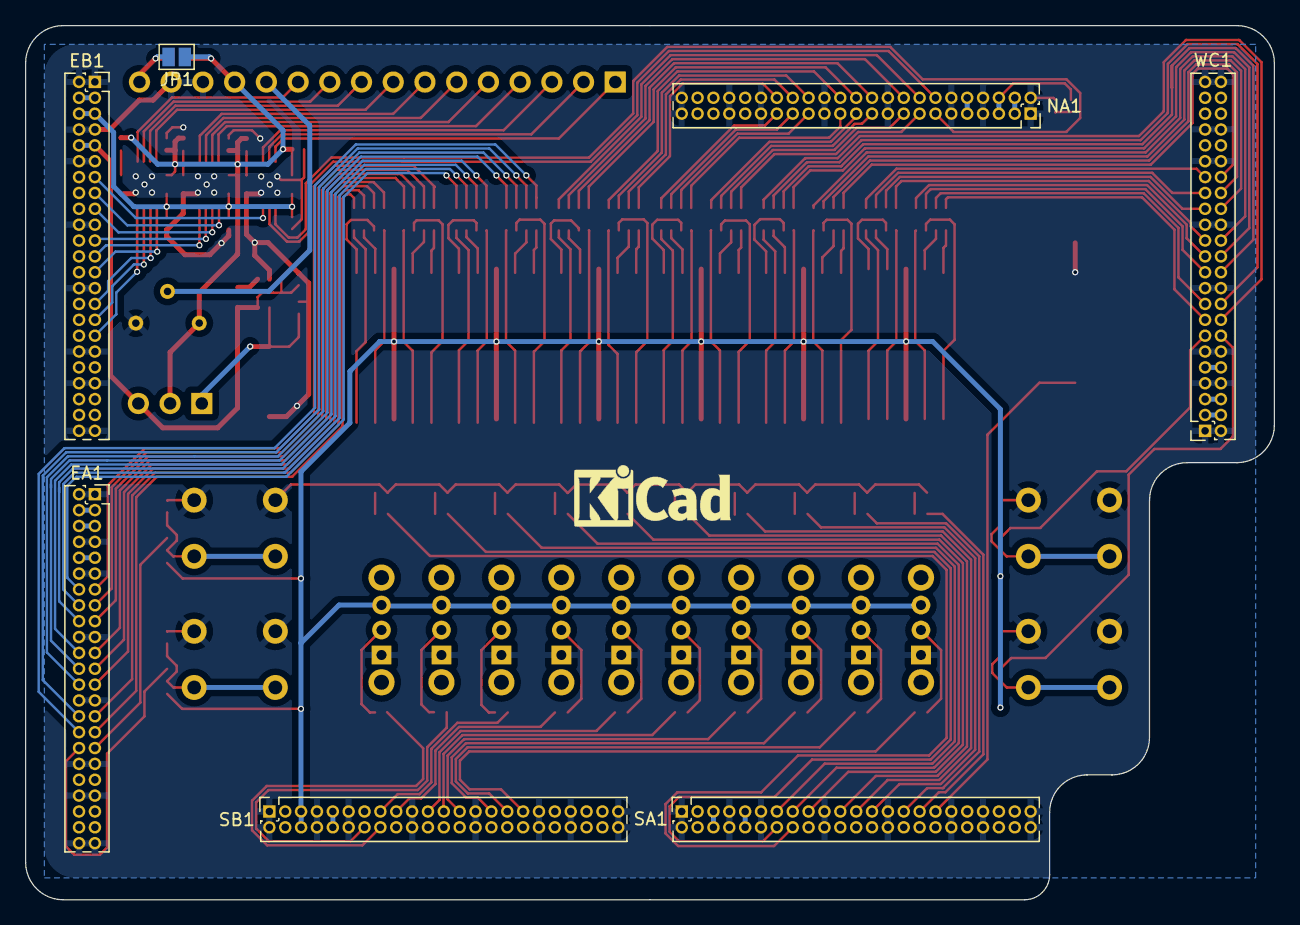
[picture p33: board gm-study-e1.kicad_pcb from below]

Board: 2 copper layers, 100.0 x 70.0 mm, 111 parts (8 on the bottom side), 193 nets.

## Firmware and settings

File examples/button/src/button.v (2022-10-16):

// -------------------------------------------------------
// button.v    gm-study-e1 demo program    @20220924 fm4dd
//
// Requires: LEDs, Push Buttons, 7-Segment modules, clk
//
// Description:
// ------------
// This program runs a light from LED0 to LED9, or back.
// pushbutton PB0 changes the speed between 1, 2, 4, 8Hz.
// pushbutton PB1 reverses the running light direction.
// The pushbuttons are debounced. Two 7-Segment modules
// show speed (HEX4: 0-3) and the direction (HEX5: F/b).
// -------------------------------------------------------
module button(
   input wire clk,
   input wire rst,
   input wire [2:0] stbtn,
   output wire [9:0] stled,
   output wire [7:0] sthex4,
   output wire [7:0] sthex5
);

// -------------------------------------------------------
//  REG/WIRE declarations
// -------------------------------------------------------
wire [4:0] data_0;
wire [4:0] data_1;
reg [9:0] lednum;
reg [22:0] div;
reg [1:0] mode;
reg speed;
reg dir;

// -------------------------------------------------------
//  Structural coding
// -------------------------------------------------------
assign stled = ~lednum;

// -------------------------------------------------------
//  Module hexdigit: Creates the LED pattern from 3 args:
// in:  0-15 displays the hex value from 0..F
//      16 = all_on
//      17 = - (show minus sign)
//      18 = _ (show underscore)
//      19 = S
//     >19 = all_off
// dp:  0 or 1, disables/enables the decimal point led
// out: bit pattern result driving the 7seg module leds
// -------------------------------------------------------
hexdigit h0 (data_0, 1'b0, sthex4);
hexdigit h1 (data_1, 1'b0, sthex5);
assign  data_0 = mode;
assign  data_1 = dir? 5'd11 : 5'd15;

// -------------------------------------------------------
// Module get_speed: Creates a clock derivate based on the
// div factor, returned into register speed.
// -------------------------------------------------------
get_speed sp (clk, rst, div, speed);

// -------------------------------------------------------
// Module debounce: get a clean push-button state signal
// -------------------------------------------------------
reg btn0, btn1;
wire btn0_down, btn1_down;
wire btn0_up, btn1_up;

debounce d0 (stbtn[0], clk, btn0, btn0_down, btn0_up);
debounce d1 (stbtn[1], clk, btn1, btn1_down, btn1_up);

always @(posedge clk or negedge rst)
begin
  if (!rst) begin
    mode <= 2'd0;
    dir <= 1'b0;
  end
  else begin
    if(btn0_down) mode = mode + 1; // increment mode
    if(btn1_down) dir = ~dir;      // change direction
  end
end

always @(posedge speed or negedge rst)
begin
  if(!rst) begin
    lednum = 10'b1111111110;  // LED seed
  end
  else begin
    case (mode)
      0: div = 23'd312499;  // 16Hz
      1: div = 23'd624999;  //  8Hz
      2: div = 23'd1249999; //  4Hz
      3: div = 23'd2499999; //  2Hz
    endcase
    if(!dir)   // forward direction
      if(lednum != 10'b0111111111) begin
        lednum[9] = lednum[8];
        lednum[8] = lednum[7];
        lednum[7] = lednum[6];
        lednum[6] = lednum[5];
        lednum[5] = lednum[4];
        lednum[4] = lednum[3];
        lednum[3] = lednum[2];
        lednum[2] = lednum[1];
        lednum[1] = lednum[0];
        lednum[0] = 1'b1;
      end
      else lednum = 10'b1111111110;
    else begin  // backward direction
      if(lednum != 10'b1111111110) begin
        lednum[0] = lednum[1];
        lednum[1] = lednum[2];
        lednum[2] = lednum[3];
        lednum[3] = lednum[4];
        lednum[4] = lednum[5];
        lednum[5] = lednum[6];
        lednum[6] = lednum[7];
        lednum[7] = lednum[8];
        lednum[8] = lednum[9];
        lednum[9] = 1'b1;
      end
      else lednum = 10'b0111111111;
    end
  end
end
endmodule


// -------------------------------------------------------
// Module get_speed creates a lower frequency based on div
// -------------------------------------------------------
module get_speed(
  input wire clk,
  input wire rst,
  input reg [22:0] div,
  output reg clk_out
);

reg [22:0] count;

always @(posedge clk or negedge rst)
begin
  if (!rst) begin
    clk_out = 1'b1;
    count = 0;
  end
  else begin 
    count <= count + 1;
    if(count == div) begin
      count <= 0;
      clk_out <= ~clk_out;
    end
  end
end
endmodule

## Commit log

2022-09-25 repo init
    [20220916-gm-study-e1-smd-bom.xlsx, 20220918-gm-study-e1-tht-bom.xlsx, data-in.kicad_sch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]
2022-10-01 verilog examples
    [data-in.kicad_sch, data-out.kicad_sch, gm-study-e1-blocks.dxf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]
2022-10-16 file updates
    [20220916-gm-study-e1-smd-bom.xlsx, 20220918-gm-study-e1-tht-bom.xlsx, 20221015-gm-study-e1-smd-bom.xlsx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]
2023-03-26 New THT PCB v1.1 updates J1 level translation IC
    [20230325-gm-study-e1-tht-bom.xlsx, data-in.kicad_sch, data-out.kicad_sch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]
2023-03-26 New SMB PCB v1.1 updates J1 level translation IC
    [20230326-gm-study-e1-smd-bom.xlsx, data-in.kicad_sch, data-out.kicad_sch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]
